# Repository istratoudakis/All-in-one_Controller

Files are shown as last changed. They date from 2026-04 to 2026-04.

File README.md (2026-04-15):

# All-in-One Productivity & AI Controller 🚀
### Developed for ΣΦΗΜΜΥ 17 / Pre-ΣΦΗΜΜΥ 10

A modular hardware-software ecosystem designed to streamline productivity by combining physical controls with a Python-based AI bridge. 

## 🛠 Project Overview
This project features an **ESP32-based controller** that interfaces with a Windows environment. It manages system functions (volume, app control) and integrates **Google Gemini AI** for voice-activated commands and intelligent task parsing.

## ✨ Key Features
- **Hardware Interface:** 13 mechanical buttons & a high-precision rotary encoder.
- **Custom GUI:** A 3.5" TFT (ILI9488) display running optimized C++ firmware.
- **Python Broker:** A robust serial bridge that handles system calls, Spotify API, and Discord integration.
- **AI Integration:** Voice-to-Command processing via Google Gemini AI.
- **Audio Processing:** Real-time noise calibration for high-accuracy voice recognition.

## 📂 Repository Structure
- `/Firmware`: ESP32 C++ source code (Arduino/PlatformIO).
- `/Python_Backend`: The "Broker" script, API handlers, and GUI.
- `/Hardware`: 3D models (.STL) and circuit diagrams.

## ⚙️ Installation & Setup

### 1. Hardware Setup
Flash the ESP32 with the code found in the `/Firmware` directory. Ensure you have the `TFT_eSPI` and `Adafruit_MCP23X17` libraries installed.

### 2. Python Backend
Install the necessary dependencies:
```bash
pip install -r requirements.txt

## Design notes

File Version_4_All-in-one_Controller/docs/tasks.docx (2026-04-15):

Task 1: Το "Serial Bridge" (Επικοινωνία Python-ESP32)

Πρέπει να φτιάξεις έναν κώδικα που "ακούει" συνεχώς τη σειριακή θύρα χωρίς να κολλάει το υπόλοιπο πρόγραμμα.

- Τι να ψάξεις: "Python pyserial read line example", "Python serial.Serial documentation".
- Τι να προσέξεις: Μάθε πώς να ορίζεις το baudrate (συνήθως 115200) και το timeout.
- Πρόκληση: Ψάξε πώς να κάνεις το loop σου "non-blocking" ώστε να μπορείς να κάνεις κι άλλα πράγματα ταυτόχρονα.

Task 2: Master Volume Control (Windows API)

Εδώ θα συνδέσεις το script σου με το λειτουργικό σύστημα.

- Τι να ψάξεις: "Python pycaw change master volume", "pycaw library examples GitHub".
- Τι να προσέξεις: Η pycaw δουλεύει με τιμές σε Decibels (που είναι λογαριθμικές). Ψάξε πώς να τις μετατρέψεις σε ένα απλό ποσοστό 0-100%.
- Βιβλιοθήκη: pycaw, comtypes, ctypes.

Task 3: Media Keys (Spotify Play/Pause/Next)

Πρέπει να προσομοιώσεις το πάτημα των "ειδικών" πλήκτρων του πληκτρολογίου.

- Τι να ψάξεις: "Python pyautogui press media play pause", "Python keyboard library media keys".
- Τι να προσέξεις: Η pyautogui είναι πιο εύκολη, αλλά η βιβλιοθήκη keyboard είναι πιο γρήγορη. Διάλεξε όποια σε βολεύει.

Task 4: Gemini AI Integration

Εδώ θα υλοποιήσεις τη "νοημοσύνη".

- Τι να ψάξεις: "Google Generative AI Python SDK quickstart", "Gemini API key setup".
- Τι να προσέξεις: Δες πώς λειτουργεί το model.generate_content.
- Bonus: Αν θες φωνητική εντολή, ψάξε τη βιβλιοθήκη SpeechRecognition και δες πώς να μετατρέπεις τον ήχο από το μικρόφωνο σε κείμενο (recognize_google).

Task 5: Spotify Web API (Για πληροφορίες τραγουδιού)

Αν θες ο φίλος σου να δείχνει στην οθόνη τον τίτλο του τραγουδιού, η Python πρέπει να τον "τραβήξει" από το Spotify.

- Τι να ψάξεις: "Spotipy documentation", "Spotify Developer Dashboard create app".
- Τι να προσέξεις: Θα χρειαστείς ένα Client ID και ένα Client Secret. Ψάξε τη μέθοδο current_user_playing_track.

Task 6: Το Πρωτόκολλο (Handshake)

Είναι ο τρόπος που θα μιλάς στον φίλο σου.

- Τι να ψάξεις: "String parsing in Arduino", "Python string formatting for serial".
- Task: Όρισε μια δομή. Π.χ. αν στείλεις από την Python [VOL:50], ο φίλος σου στο ESP32 πρέπει να ξέρει να απομονώσει τον αριθμό 50 για να τον δείξει στην οθόνη.

Πώς να ξεκινήσεις σήμερα (χωρίς hardware):

1. Εγκατάστησε το VS Code.
2. Φτιάξε ένα virtual environment (python -m venv venv).
3. Ξεκίνα με το Task 2 (Volume). Είναι το πιο εύκολο για να επιβεβαιώσεις ότι το script σου "μιλάει" στα Windows.  Όσο το project μεγαλώνει και ξεφεύγει από τον κώδικα, η σωστή οργάνωση είναι αυτή που ξεχωρίζει έναν χομπίστα από έναν Engineer. Αν τα έχεις όλα "χύμα", θα χάσεις την μπάλα όταν θα πρέπει να γράψεις την τεχνική αναφορά.
4. Ακολουθεί η επαγγελματική δομή για να ενσωματώσεις έγγραφα, σχέδια και CAD αρχεία:
5. Η Επαγγελματική Δομή Φακέλου
6. Plaintext
7. SmartController/
8. ├── .venv/ # Το virtual environment (Python)
9. ├── src/ # ΜΟΝΟ ο πηγαίος κώδικας (main.py, κλπ)
10. ├── docs/ # Έγγραφα (Τεχνική αναφορά, manual, .docx, .pdf)
11. ├── hardware/ # Τα πάντα για το "σώμα" του controller
12. │ ├── schematics/ # Σχέδια κυκλωμάτων (π.χ. από Wokwi, KiCad, Fritzing)
13. │ ├── cad/ # Αρχεία για το κουτί (3D models, .stl, .step)
14. │ └── datasheets/ # PDF με τα specs των εξαρτημάτων (ESP32, Encoder)
15. ├── assets/ # Εικόνες, εικονίδια για το GUI της οθόνης
16. ├── .gitignore # Λίστα αρχείων που δεν ανεβαίνουν στο Git
17. ├── requirements.txt # Βιβλιοθήκες Python
18. └── README.md # Η κεντρική παρουσίαση του project
20. Γιατί να το κάνεις έτσι;
21. Φάκελος docs/: Εκεί θα έχεις το προσχέδιο της εργασίας σου σε .docx. Όταν τελειώσεις, κάνε "Export as PDF" και κράτα το εκεί ως "Final_Report.pdf". Είναι η εικόνα σου προς τους κριτές.
22. Φάκελος hardware/: * Στο schematics/ αποθήκευσε ένα screenshot από το κύκλωμά σου στο Wokwi.
23. Στο cad/ θα βάλεις τα αρχεία αν αποφασίσετε να εκτυπώσετε το κουτί σε 3D printer.
24. Φάκελος assets/: Αν ο φίλος σου φτιάξει ένα όμορφο logo ή εικονίδια για την OLED οθόνη, πρέπει να είναι κάπου συγκεντρωμένα και όχι μέσα στον φάκελο με τον κώδικα.
26. Πώς να τα φτιάξεις γρήγορα στο VS Code
27. Μπορείς να χρησιμοποιήσεις πάλι το τερματικό (CMD) για να δημιουργήσεις τους φακέλους αστραπιαία:
28. DOS
29. mkdir docs
30. mkdir hardware
31. mkdir hardware\schematics
32. mkdir hardware\cad
33. mkdir hardware\datasheets
34. mkdir assets
35. Pro Tip: Οργάνωση "Versions"
36. Μην ονομάζεις τα αρχεία σου report_v1.docx, report_v2_final.docx. Κράτα ένα όνομα (π.χ. Technical_Report.docx) και αν θέλεις να κρατάς ιστορικό, χρησιμοποίησε το Git (αν το κατέχεις) ή απλά φτιάξε έναν υποφάκελο archive μέσα στο docs.
37. Πώς σου φαίνεται αυτή η δομή; Αν θέλεις, μπορούμε να ξεκινήσουμε να γεμίζουμε τον φάκελο hardware/schematics ορίζοντας το Pinout του ESP32, ώστε να ξέρεις πού θα συνδέσεις το κάθε control!

Είναι φανταστικό που έχετε χωρίσει τους ρόλους έτσι! Αυτό θυμίζει κανονική ομάδα Product Development. Επειδή είστε τρεις και δουλεύετε σε διαφορετικά κομμάτια (Hardware/Simulation, Python/AI, και Production), ο "συνδετικός κρίκος" σας είναι το Interface (η διεπαφή).

Δείτε πώς θα "κουμπώσετε" τη δουλειά σας για να μην χαθείτε:

1. Η Τεχνική Σύνδεση (GitHub ή Shared Folder)

Για να μην στέλνετε αρχεία με email ή Discord (που είναι εφιάλτης), πρέπει να χρησιμοποιήσετε ένα Version Control System.

- Η λύση "Pro": Φτιάξτε ένα GitHub Repository. Εσύ θα ανεβάζεις τον κώδικα Python, ο "Hardware" φίλος σου θα ανεβάζει τα αρχεία του Wokwi ή τον κώδικα C++, και ο "Production" φίλος σου θα ανεβάζει τα assets (εικονίδια, PDFs).
- Η λύση "Easy": Ένας κοινός φάκελος στο Google Drive ή OneDrive, αλλά προσοχή να μην σβήνει ο ένας τα αρχεία του άλλου!

2. Πώς συνδέονται οι ρόλοι σας στην πράξη;

Εσύ (Python & AI Logic)

Είσαι ο "εγκέφαλος". Παίρνεις σήματα από το hardware και δίνεις εντολές στα Windows και το Gemini.

- Τι δίνεις στους άλλους: Πρέπει να πεις στον Hardware φίλο σου: "Θέλω να μου στέλνεις τη λέξη 'GEMINI_REQ' όταν πατιέται το κουμπί του AI".

Ο "Virtual Feedback" Φίλος (Hardware & Simulation)

Είναι υπεύθυνος για το πώς "νιώθει" ο χρήστης τη συσκευή.

- Τι κάνει: Στήνει το Wokwi, τις οθόνες (OLED) και τα κουμπιά.
- Η σύνδεση: Όταν εσύ (Python) παίρνεις μια απάντηση από το Gemini, πρέπει να τη στέλνεις πίσω σε αυτόν (μέσω Serial) για να την εμφανίσει στην εικονική οθόνη του.

Ο "Streaming & Production" Φίλος (Documentation & Presentation)

Αυτός είναι ο "σκηνοθέτης" και ο "συγγραφέας".

- Τι κάνει: Καταγράφει το demo (screen recording του Wokwi και του VS Code), φτιάχνει το βίντεο της παρουσίασης και οργανώνει την τεχνική αναφορά (το .docx που λέγαμε).
- Η σύνδεση: Χρειάζεται από εσένα screenshots του κώδικα και από τον άλλον screenshots του κυκλώματος.

3. Το "Συμβόλαιο" (Communication Protocol)

Για να δουλέψετε ταυτόχρονα, φτιάξτε ένα απλό αρχείο κειμένου (π.χ. protocol.md) όπου θα γράψετε:

Ενέργεια Hardware | Serial Command (προς Python) | Python Action
Πάτημα Κουμπιού 1 | PLAY_PAUSE | pyautogui.press('playpause')
Περιστροφή Encoder | VOL_UP / VOL_DOWN | change_volume(0.05)
Long Press Button 2 | AI_MODE | Ενεργοποίηση Gemini

Πώς να ξεκινήσετε τη σύνδεση ΣΗΜΕΡΑ:

1. Shared Workspace: Φτιάξτε έναν φάκελο στο GitHub ή Drive με τη δομή που συζητήσαμε (src, docs, hardware).
2. Define Pins: Ο Hardware φίλος πρέπει να σου στείλει μια λίστα: "Το κουμπί Play είναι στο Pin 4, το Volume στο Pin 5".
3. The "Mock" Test: Εσύ φτιάξε μια λειτουργία που προσομοιώνει το σήμα του φίλου σου, ώστε να μπορείς να γράφεις κώδικα ακόμα κι αν εκείνος δεν έχει τελειώσει το Wokwi.

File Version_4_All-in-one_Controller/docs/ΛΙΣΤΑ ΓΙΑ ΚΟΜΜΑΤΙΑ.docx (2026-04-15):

### 🛒 Η Τελική Λίστα (Τι πρέπει να παραγγείλετε τώρα)

1. Καπάκια (Knobs) για τα Rotary Encoders: Τα EC11 που έχετε στη λίστα έχουν απλώς έναν γυμνό μεταλλικό άξονα. Χωρίς το πλαστικό ή αλουμινένιο καπάκι, θα σας πονάνε τα δάχτυλα να τα γυρίσετε. Προσθέστε 2 τεμάχια.
2. I/O Expander (Μοντούλα MCP23017 ή PCF8574): Υπερ-απαραίτητο! Ας κάνουμε τα μαθηματικά: 10 κουμπιά + 1 διακόπτης + 6 pins (για τα 2 rotaries) + ~5-6 pins για την οθόνη = 22+ pins. Το ESP32 έχει μεν αρκετά, αλλά κάποια από αυτά (τα λεγόμενα strapping pins όπως τα 0, 2, 5, 12) αν πατηθεί κατά λάθος το κουμπί τους την ώρα που ανοίγει η συσκευή, το ESP32 θα "κολλήσει" και δεν θα κάνει boot. Με ένα MCP23017, γλιτώνετε όλο αυτό το άγχος συνδέοντας τα 10 κουμπιά πάνω του. Προσθέστε 1 τεμάχιο.
3. Κεραμικοί Πυκνωτές 100nF (0.1uF): Είναι πάμφθηνοι (μερικά λεπτά του ευρώ). Θα χρειαστείτε καμιά 20αριά για να τα βάλετε παράλληλα με τα κουμπιά και τα rotaries. Κάνουν το λεγόμενο "Hardware Debouncing" ώστε να μην κάνει "διπλό κλικ" από μόνο του όταν πατάτε το κουμπί μία φορά.
4. Υλικά Συναρμολόγησης (Αν δεν τα έχετε ήδη στο εργαστήριο):
  - 1x Breadboard (Ράστερ): Για να τα συνδέσετε όλα πρόχειρα και να γράψουμε τον κώδικα πριν πιάσετε κολλητήρι.
  - Καλώδια Dupont: 1 σετ Male-to-Male και 1 σετ Female-to-Male για τις δοκιμές.
  - Διάτρητες πλακέτες (Protoboards): 2-3 κομμάτια για να κολλήσετε τα πάντα πάνω τους στο τελικό στάδιο.
  - Pin Headers (Αρσενικά/Θηλυκά): Για να "κουμπώσετε" το ESP32 και την οθόνη πάνω στην πλακέτα χωρίς να τα κολλήσετε μόνιμα (ώστε αν καεί κάτι, να το αλλάξετε εύκολα).

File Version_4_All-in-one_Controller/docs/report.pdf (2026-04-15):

## Σχεδιασμός και Υλοποίηση All-in-one Controller με LCD Screen και Ενσωμάτωση AI

Όνομα Ομάδας: Τα παιδιά από την Πάτρα

### Μέλη:

### Γεώργιος Σικαλιάς

### Ιάσονας Στρατουδάκης

### Κωσταντίνος Παπαδημητρίου

ABSTRACT

Η συγκεκριμένη εργασία ασχολείται με τη σχεδίαση και την υλοποίηση μιας ολοκληρωμένης συσκευής All-in-one Controller, στο πλαίσιο του διαγωνισμού PreΣΦΗΜΜΥ 10 του συνεδρίου ΣΦΗΜΜΥ 17. Η συσκευή έχει ως πυρήνα τον microcontroller ESP32 DevKit V1 σε συνδυασμό με μία οθόνη TFT LCD 3.5” eSPI και έναν I/O Expander 16-bit MCP 23017 πρωτοκόλλου I2C. Η συσκευή επιτρέπει τον έλεγχο του λειτουργικού συστήματος και γενικώς των multimedia, shortcuts για εφαρμογές όπως Spotify, Zoom και Discord αλλά και για το λογισμικό streaming Streamlabs OBS, καθώς και real-time visual response και feedback μέσω της οθόνης. Τα μέσα αλληλεπίδρασης συσκευής-χρήστη περιλαμβάνουν: 13 διακόπτες τύπου button, ένα rotary encoder και διεπαφή φωνητικών εντολών με επεξεργασία φυσικής γλώσσας (NLP) που αξιοποιεί το Gemini AI για βελτιστοποίηση της κατανόησης των εντολών. Ο προγραμματισμός του microcontroller και της οθόνης είναι σε Arduino C++ με τη διασύνδεση του με το λειτουργικό σύστημα και τις εφαρμογές στο PC να έχουν υλοποιηθεί σε Python. Η συσκευή αυτή είναι τοποθετημένη σε ένα 3D printed fully modular κουτί σχεδιασμένο σε περιβάλλον CAD, το οποίο εκτός από την πρακτικότητα του στην συναρμολόγηση-αποσυναρμολόγηση προσδίδει σύγχρονη αισθητική στη συσκευή. Ο συνολικός προϋπολογισμός της συσκευής ανέρχεται στα 61.34€.

CCS CONCEPTS • Computer systems organization ~ Embedded systems • Human-centered computing ~ Interaction devices • Computing methodologies ~ Artificial intelligence

Additional Keywords and Phrases: ESP32, MCP23017, Gemini AI, Google LLM, Διασύνδεση Ανθρώπου-Μηχανής (HCI), Python Serial Bridge, Έλεγχος Πολυμέσων, LCD Screen GUI, Real-time Visual Feedback.

ACM Reference Format:
Γεώργιος Σικαλιάς, Ιάσονας Στρατουδάκης, Κωσταντίνος Παπαδημητρίου. 2026. Σχεδιασμός και Υλοποίηση All-in-one Controller με LCD Screen και Ενσωμάτωση AI. PreΣΦΗΜΜΥ 10, ΣΦΗΜΜΥ 17. Πάτρα, Ελλάδα.

## Contents

### 1 INTRODUCTION

### 1.1 Concept

Με τη συμμετοχή μας στο διαγωνισμό PreΣΦΗΜΜΥ 10 αποφασίσαμε να ασχοληθούμε με τις 3 από τις 4 αναγραφόμενες στην εκφώνηση λειτουργίες (τουλάχιστον 2 υποχρεωτικές):
- PC & Multimedia Control
- Streaming & Production
- Visual Feedback
Η επιλογή αυτών των λειτουργιών έγινε βάσει του μεγάλου impact που έχει στην καθημερινή ψηφιακή ζωή του μηχανικού η απλοποίηση και αυτοματοποίηση των διαδικασιών αυτών. Είναι πράγματι πολύ πρακτικός ο έλεγχος του λειτουργικού συστήματος και των εφαρμογών του μέσω ενός εξωτερικού συγκεντρωμένου Allin-one Controller. Επομένως, θέσαμε ως προτεραιότητα τη σχεδίαση και υλοποίηση των λειτουργιών αυτών με προτεραιότητα την αύξηση της παραγωγικότητας του χρήστη. Φυσικά, λάβαμε υπόψιν μας ως βασικό άξονα το οικονομικό κόστος το οποίο επιβαλλόταν να ελαχιστοποιηθεί, χωρίς όμως να υποβαθμιστεί η συνολική ποιότητα και λειτουργικότητα της συσκευής. Έτσι, δημιουργήσαμε από την αρχή μία value for money ανταγωνιστική συσκευή, η οποία ενσωματώνει ένα μεγάλο πλήθος διεργασιών.

### 1.2 Επιλογή hardware

Ως πυρήνας της συσκευής επιλέχθηκε ο microcontroller ESP32 DevKit V1 επειδή συνδυάζει υψηλή υπολογιστική ισχύ (Dual Core, Clock Speed: 240 MHz, SRAM: 520 KB, Flash Memory: 4 MB) και εξαιρετικά χαμηλό κόστος ( Ενότητα 1.3). Καθώς όμως παρά το μεγάλο πλήθος των pins του ESP32 γρήγορα συνειδητοποιήσαμε ότι αυτά δεν επαρκούσαν, κατευθυνθήκαμε προς την ενσωμάτωση ενός I/O Expander και συγκεκριμένα του MCP 23017 με πρωτόκολλο I2C. Η επιλογή του MCP23017 δεν έγινε μόνο για την εξοικονόμηση pins, αλλά και για τη μείωση της πολυπλοκότητας της καλωδίωσης. Μέσω του διαύλου I2C (Serial Data - SDA, Serial Clock - SCL), ο ESP32 διαχειρίζεται το σύνολο των 13 εισόδων χρησιμοποιώντας μόνο 2 pins, αφήνοντας τους υπόλοιπους πόρους ελεύθερους για την απαιτητική οδήγηση της TFT οθόνης μέσω του πρωτοκόλλου SPI.
Παράλληλα, επειδή θεωρήσαμε πολύ σημαντική την οπτική απεικόνιση, επενδύσαμε ένα σημαντικό μέρος του συνολικού προϋπολογισμού σε μία ποιοτική ευμεγέθη οθόνη 3.5”, ώστε οι πληροφορίες να είναι διακριτές και ευανάγνωστες στο πλαίσιο ενός απλού και user-friendly GUI. Με αυτό τον τρόπο, από ένα απλό panel κουμπιών, η συσκευή απέκτησε τη δυνατότητα να προσφέρει live visual feedback με ανανέωση ανά δευτερόλεπτο για λόγους ακρίβειας και αξιοπιστίας.

### 1.3 Σχεδίαση Software

Καταρχάς, για τα βασικά Multimedia θα έπρεπε να αξιοποιήσουμε τα δεδομένα του λειτουργικού συστήματος (ένταση ήχου, ένταση μικροφώνου, κάμερα, χρήση CPU, RAM GPU). Στη συνέχεια, αποφασίσαμε ότι θα ενσωματώσουμε τις παρακάτω εφαρμογές:
- Spotify
- Discord
- Zoom
- Streamlabs OBS
Για τη διασύνδεση όλων αυτών των εφαρμογών θα έπρεπε να υλοποιήσουμε μία serial bridge, η οποία να επικοινωνεί με τον ESP32 μέσω USB σε micro USB καλωδίου.
Για λόγους πρακτικότητας επιλέξαμε να υλοποιήσουμε τα παραπάνω σε Python στο Visual Studio Code IDE καθώς εκτελούνται αποκλειστικά στο PC, χωρίς όμως αυτό να μας δημιουργήσει προβλήματα με τον χρόνο απόκρισης. Ο κώδικας του ESP32 υλοποιήθηκε σε Arduino C++ στο Arduino IDE και περιλαμβάνει όλες τις λειτουργίες που επιλέξαμε καθώς και δυνατότητα ενσύρματης επικοινωνίας με τον υπολογιστή μέσω του serial bridge.

### 1.4 Hardware Συσκευής και Κοστολόγηση

No. | Όνομα Component | Link | Κόστος
1 | Espressif ESP32D Development Kit Wifi & Bluetooth | https://www.skroutz.gr/s/37404120/Espressif-ESP32D-Development-Kit-WiFi-Bluetooth.html (https://www.skroutz.gr/s/37404120/Espressif-ESP32D-Development-Kit-WiFi-Bluetooth.html) | 9.20€
1 | Οθόνη LCD 3.5” (46751) | https://www.skroutz.gr/s/46180029/Othoni-LCD-3-5-46751.html (https://www.skroutz.gr/s/46180029/Othoni-LCD-3-5-46751.html) | 25.00€
1 | Microchip I/O Expander (MCP23017-E/SP) | https://www.skroutz.gr/s/45257010/Microchip-I-O-Expander-MCP23017-E-SP.html (https://www.skroutz.gr/s/45257010/Microchip-I-O-Expander-MCP23017-E-SP.html) | 4.50€
1 | Rotary Encoder Module with Demo Code Module για Arduino KY-040 | https://www.skroutz.gr/s/40170309/Rotary-Encoder-Module-With-Demo-Code-Module-gia-Arduino-KY-040.html (https://www.skroutz.gr/s/40170309/Rotary-Encoder-Module-With-Demo-Code-Module-gia-Arduino-KY-040.html) | 2.00€
2 | Haitronic Διακόπτης Μπουτόν 10τμχ | https://www.skroutz.gr/s/52173703/Haitronic-Diakoptis-Mpouton-HR0320-10tmch.html (https://www.skroutz.gr/s/52173703/Haitronic-Diakoptis-Mpouton-HR0320-10tmch.html) | 1.00€
2 | Optum Solderless Breadboard (MB-102) | https://www.skroutz.gr/s/30576026/Optum-Solderless-Breadboard-MB-102.html (https://www.skroutz.gr/s/30576026/Optum-Solderless-Breadboard-MB-102.html) | 4.64€
1 | Haitronic Half-Size Solderless Breadboard 400 θέσεων 82x54mm | https://www.skroutz.gr/s/28640210/Haitronic-Half-Size-Solderless-Breadboard-400-theseon-82x54mm.html (https://www.skroutz.gr/s/28640210/Haitronic-Half-Size-Solderless-Breadboard-400-theseon-82x54mm.html) | 1.99€
3 | Dupont M-F Καλώδιο 0.2m OEM478 10τμχ | https://www.skroutz.gr/s/64645470/dupont-m-f-kalodio-0-2m-oem478-10tmch.html (https://www.skroutz.gr/s/64645470/dupont-m-f-kalodio-0-2m-oem478-10tmch.html) | 2.25€
45/65 | Arduino 65pcs Jumper Wire Cable Kit for Solderless Breadboard Connections | https://www.skroutz.gr/s/28756792/Arduino-65pcs-Jumper-Wire-Cable-kit-for-Solderless-Breadboard-Connections.html (https://www.skroutz.gr/s/28756792/Arduino-65pcs-Jumper-Wire-Cable-kit-for-Solderless-Breadboard-Connections.html) | 2.17€

14 | Πυκνωτής Κεραμικός 104 100nf | https://www.skroutz.gr/s/58711482/Pyknotis-Keramikos-104-100nf.html (https://www.skroutz.gr/s/58711482/Pyknotis-Keramikos-104-100nf.html) | 0.70€
0.435kg | Esun PLA 3D Printer Filament 1.75mm Μαύρο 1kg 1τμχ (Spool) | https://www.skroutz.gr/s/59842404/esun-pla-3d-printer-filament-1-75mm-mayro-1kg-1tmch-spool.html (https://www.skroutz.gr/s/59842404/esun-pla-3d-printer-filament-1-75mm-mayro-1kg-1tmch-spool.html) | 6.92€
1 | Ρεύμα/Φθορές 3D Printer | - | 1.00€
1 | Λογισμικό | - | 0.00€
61.34€

### 2 HARDWARE DESIGN

### 2.1 Τροφοδοσία και Ισχύς

Η κύρια τροφοδοσία (5V) γίνεται μέσω του καλωδίου USB σε micro USB από το PC στο ESP32. Το ESP32 εν συνεχεία λειτουργεί ως κόμβος τροφοδοσίας, αφού όλα τα υπόλοιπα components (LCD screen, I/O expander, rotary controller) συνδέονται σε pins του, είτε άμεσα, είτε έμμεσα μέσω breadboard. Επειδή όμως τα υπόλοιπα στοιχεία λειτουργούν στα 3.3V, το ESP32 υποβιβάζει τη τάση στα 3.3V (μέσω LDO AMS1117) και οι συνδέσεις με τα components γίνονται μέσω του pin 3V3.
Για να φιλτράρουμε τον ηλεκτρικό θόρυβο που προκαλείται από τις εναλλαγές του σήματος(από λογικό ‘0’ σε λογικό ‘1’ και αντίστροφα) χρησιμοποιήσαμε κεραμικούς πυκνωτές των 100nF στους διακόπτες τύπου button. Έτσι, αποφεύγεται το bouncing των buttons κατά το press και διασφαλίζεται η αξιοπιστία και η λειτουργικότητα του κυκλώματος.

### 2.2 Διεπαφές Επικοινωνίας

Μεταξύ των components συνυπάρχουν 2 πρωτόκολλα επικοινωνίας:
1. I2C Bus μεταξύ MCP23017 και ESP32 για έλεγχο των pins
2. SPI Bus μεταξύ LCD οθόνης και ESP32 για έλεγχο του GUI της οθόνης Ακολουθεί μία σύντομη επεξήγηση της λειτουργίας των πρωτοκόλλων που αξιοποιήσαμε.

2.2.1 I2C Bus

Το I2C προσφέρει τη δυνατότητα ελέγχου και των 13 κουμπιών με μόνο 2 γραμμές σήματος: την SDA (Serial Data) και την SCL (Serial Clock). Με αυτόν τον τρόπο εξοικονομούνται 11 pins του ESP32 (2 pins αντί για 13), κάτι ιδιαίτερα πρακτικό για τη σχεδίαση του embedded συστήματος. Η επικοινωνία διεξάγεται στα 400kHz, συχνότητα η οποία εξασφαλίζει αμελητέο latency.
Ακολουθεί το κυκλωματικό διάγραμμα των συνδέσεων μεταξύ του MCP23017 και του ESP32:

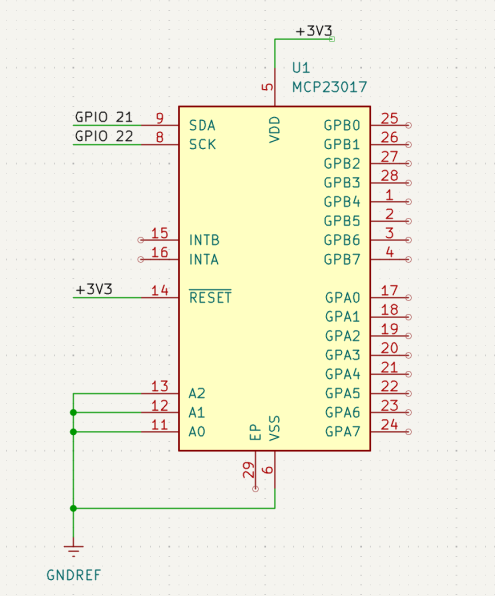
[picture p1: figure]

Συνδέσεις του MCP23017 στο ESP32 [2.2.1]

2.2.2 SPI Bus
Το πρωτόκολλο SPI χρησιμοποιείται για τη μεταφορά μεγάλου όγκου πληροφορίας στην οθόνη (480x320 pixel, αυτόνομα για κάθε pixel). Το SPI χρησιμοποιεί 4 γραμμές σήματος: SCK (Clock), MOSI (Master Out Slave In), CS (Chip Select) και DC (Data/Command). Η επικοινωνία είναι χρονισμένη στα 40MHz, μεγαλύτερη των 400kHz του I2C, κάτι απαραίτητο για να έχουμε real-time visual feedback και συνεπακόλουθα για ομαλή ανανέωση των γραφικών στην οθόνη. Η λειτουργία της οθόνης βασίζεται στον driver ILI9488.

Ακολουθεί το κυκλωματικό διάγραμμα της διασύνδεσης της οθόνης με το ESP32:

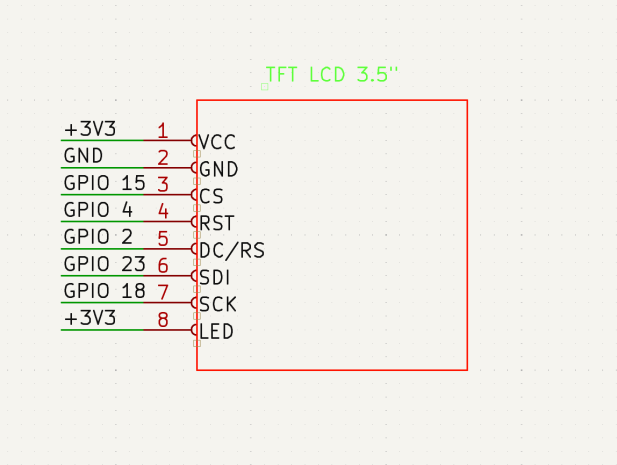
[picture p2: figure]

Συνδέσεις από την οθόνη στο ESP32 [2.2.2]

### 2.3 Διασύνδεση Εισόδων

Έχουμε 2 ειδών εισόδους: απλούς μηχανικούς διακόπτες τύπου button και ένα rotary encoder, οπότε η ανάλυσή μας θα χωριστεί σε δύο μέρη. Στη συνέχεια, θα αναλύσουμε την οργάνωση των κυκλωμάτων ανά breadboard.

2.3.1 Μηχανικοί Διακόπτες (Buttons)

Η συσκευή περιλαμβάνει 13 μηχανικούς διακόπτες, οποίοι είναι συνδεδεμένοι στις GPA και GPB θύρες του MCP23017. Οι διακόπτες λειτουργούν με active-low λογική, δηλαδή η λειτουργία διεκπεραιώνεται στο λογικό ‘0’. Σε συνδυασμό με τους πυκνωτές, το σήμα καθαρίζεται με αποτέλεσμα να μην δημιουργούνται προβλήματα θορύβου.

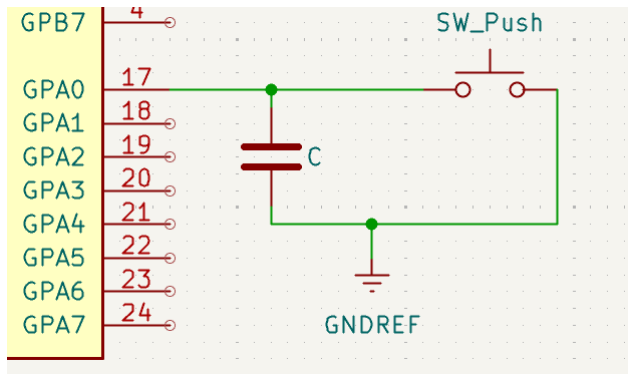
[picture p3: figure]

Κύκλωμα με διακόπτη Button

2.3.2 Περιστροφικός Κωδικοποιητής (Rotary Encoder)

Για τον έλεγχο της έντασης (Volume Up/Down) και την έναρξη/παύση (Play/Pause) χρησιμοποιήθηκε ο rotary encoder. Η λειτουργία play/pause είναι εφάμιλλη με αυτή των buttons. Για τον περιστροφικό διακόπτη όμως έχουμε διαφορετική λειτουργία. Συγκεκριμένα, ο rotary encoder παράγει δύο τετραγωνικά σήματα DT (Data) και CLK (Clock) με διαφορά φάσης 90ο
. Ανάλογα με την κατεύθυνση της περιστροφής (δεξιόστροφη ή αριστερόστροφη) συγκρίνει πιο από τα δύο σήματα αλλάζει κατάσταση πρώτο και επιλέγει αντίστοιχα αύξηση ή μείωση της έντασης του ήχου. Τα pins του rotary encoder είναι απευθείας συνδεδεμένα πάνω στα pins του ESP32 και όχι μέσω του MCP23017, όπως παρακάτω:

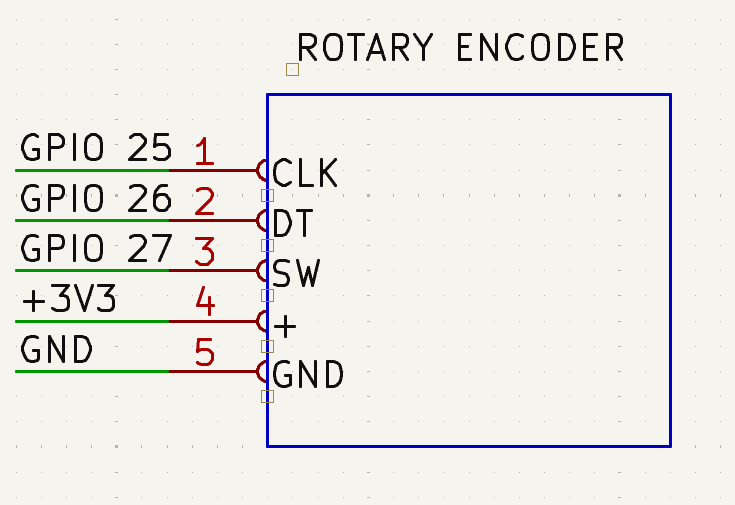
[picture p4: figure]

Συνδέσεις Rotary Encoder σε ESP32

2.3.3 Breadboards

Στην συσκευή μας χρησιμοποιήσαμε 3 breadboards: 2 κλασσικού μεγέθους και ένα του μισού μεγέθους. Στο μικρό κεντρικό breadboard έχουν γίνει οι συνδέσεις του ESP32 με την οθόνη και με το rotary encoder. Στο πάνω κλασσικό breadboard έχουν τοποθετηθεί τα 10 από τα 13 buttons, ενώ στο κάτω έχουν τοποθετηθεί τα 3 επιπλέον buttons και η σύνδεση με το MCP23017.

### 3 C++ FIRMWARE & SERIAL BRIDGE

### 3.1 Δομή Firmware

Ο κώδικας του ESP32 έχει οργανωθεί ούτως ώστε να μην αποτελεί απλά ένα σύνολο εντολών, αλλά να είναι σχεδιασμένο να λειτουργεί ως ένα multitasking σύστημα. Έτσι, για παράδειγμα, η ανανέωση της οθόνης δεν εμποδίζει την λειτουργία των buttons ή του rotary encoder.
Για την υλοποίηση του firmware χρησιμοποιήθηκαν οι βιβλιοθήκες: Wire.h, Adafruit_MCP23X17.h και TFT_eSPI.h.

### 3.2 Διαχείριση εισόδων

Ο ESP32 ελέγχει συνεχώς στον MCP23017 την κατάσταση των buttons και αν κάποιο βρεθεί στο λογικό ‘0’, τότε ενεργοποιεί την αντίστοιχη λειτουργία. Όσον αφορά το rotary encoder, για την αποφυγή απώλειας δεδομένων κατά τη γρήγορη περιστροφή, χρησιμοποιήσαμε external interrupts στα pins του ESP32. Αυτό διασφαλίζει ότι η μεταβλητή της έντασης ενημερώνεται ακαριαία, ανεξάρτητα από το τι κάνει το υπόλοιπο πρόγραμμα.

### 3.3 Σχεδίαση GUI Οθόνης

Όπως αναφέραμε και στην παράγραφο 2.2.2, το SPI είναι ρυθμισμένο στα 40MHz που σε συνδυασμό με την βιβλιοθήκη TFT_eSPI επιτρέπει την ομαλή ανανέωση των pixel της οθόνης. Για να αποφευχθεί το flickering της οθόνης, δεν ανανεώνεται ολόκληρη η οθόνη συνεχώς, αλλά μόνο τα pixel τα οποία αλλάζουν. Η οθόνη έχει χωριστεί σε 5 μέρη:
- PC Multimedia (Volume, Microphone On/Off, Camera On/Off)

- Spotify (Όνομα κομματιού – Καλλιτέχνης, progress bar που αναγράφει real-time τη χρονική στιγμή που βρίσκεται το κομμάτι)
- PC Stats (CPU - RAM - GPU usage)
- Discord (Mute/Unmute, Deafen/Undeafen)
- Gemini/Voice Command Status (Standby, Listening)

### 3.4 Σειριακό Πρωτόκολλο Επικοινωνίας

Σχεδιάσαμε ένα απλό πρωτόκολλο επικοινωνίας της μορφής <TAG:PAYLOAD>, στο οποίο το TAG προσδιορίζει την κατηγορία της εντολής και το PAYLOAD την μεταβληθείσα πληροφορία. Έτσι, με αυτό τον απλό τρόπο μπορεί και μεταβιβάζεται γρήγορα η πληροφορία από το ESP32 στο PC και αντίστροφα.

### 3.5 Λογική Serial Bridge

Η επικοινωνία ESP32 – PC είναι αμφίδρομη, οπότε η ανάλυση μας θα χωριστεί σε δύο διακριτά μέρη: από το microcontroller στο PC και από το PC στο microcontroller.
- ESP32 → PC: Μόλις ο ESP32 ανιχνεύσει κάποια μεταβολή στις εισόδους του κυκλώματος, σύμφωνα με το ενσωματωμένο firmware, οργανώνει την πληροφορία σύμφωνα με το επιλεγμένο σειριακό πρωτόκολλο επικοινωνίας και την προωθεί απευθείας στον υπολογιστή μέσω του καλωδίου USB.
- PC → ESP32: Ο ESP32 συνεχώς παρακολουθεί την σειριακή θύρα USB. Όταν εντοπίσει τον χαρακτήρα “<” διαβάζει το πακέτο πληροφορίας. Στη συνέχεια, δρομολογεί την εκάστοτε αλλαγή στη λειτουργία της συσκευής και ενημερώνει το GUI της οθόνης.
Επειδή η ταχύτητα της σειριακής είναι πολύ υψηλή (115200bps) και έχουμε μεγάλο όγκο δεδομένων, η ανάγνωση των δεδομένων γίνεται χαρακτήρα-χαρακτήρα, ώστε να μην μπλοκάρεται η λειτουργία της υπόλοιπης συσκευής. Επίσης, αν και τα δεδομένα από τις εισόδους αποστέλλονται στο PC σχεδόν ακαριαία, η ενημέρωση του GUI της οθόνης γίνεται ανά δευτερόλεπτο, ρυθμός ικανός να παρέχει μία ικανοποιητική εμπειρία χρήσης και συγχρόνως να μην υπερφορτώνει τον ESP32.
Για την αποφυγή σφαλμάτων, έχουμε δημιουργήσει δύο βασικούς μηχανισμούς ελέγχου:
1. Τα πακέτα πληροφορίας προς ανάγνωση θα πρέπει να αρχίζουν και να τελειώνουν με [ < , >].
2. Αν το TAG δεν ανήκει σε ένα προκαθορισμένο κατάλογο εντολών, τότε η εντολή απορρίπτεται. Τέλος, χρησιμοποιήθηκε λογική multithreading . Συγκεκριμένα, επειδή το voice recording είναι μία διεργασία η οποία δεσμεύει πολλούς πόρους από το ESP32 αυτό εκτελείται σε ένα ανεξάρτητο thread συνεχώς. Έτσι, αποφεύγονται οι διακοπές στην ηχογράφηση που προκαλούνται από τη συμφόρηση εντός του ESP32.

### 4 PYTHON SOFTWARE & API’S

### 4.1 Διαχείριση Λειτουργικού Συστήματος

Ο κώδικας της Python λαμβάνει συγκεκριμένα σήματα από το ESP32 βάσει του σειριακού πρωτοκόλλου επικοινωνίας και εκτελεί άμεσα τις κατάλληλες αλλαγές στο λειτουργικό σύστημα στον υπολογιστή. Συγκεκριμένα, έχουμε τις παρακάτω λειτουργίες:

- Έλεγχος ένταση ήχου: Αξιοποιούμε τη βιβλιοθήκη pycaw (Python Core Audio Windows Library), ώστε να έχουμε πρόσβαση στον ήχο των Windows. Η Python λαμβάνει εντολές από τον rotary encoder και βάσει του payload του πρωτοκόλλου ρυθμίζει το ύψος της έντασης.
- Διαχείριση μικροφώνου: Με τη χρήση του εξωτερικού προγράμματος NirCmd η Python αποκτά έλεγχο στη διαχείριση του global μικροφώνου των Windows.
- Διαχείριση κάμερας: Αξιοποιούμε τις βιβλιοθήκες pyautogui και τη ctypes που ενεργοποιεί ή απενεργοποιεί τη λειτουργία της κάμερας.
- Παρακολούθηση των πόρων: μέσω της βιβλιοθήκης psutil η Python αντλεί πληροφορίες σχετικά με την καταπόνηση του CPU και της RAM, ενώ μέσω της GPUtil την καταπόνηση της GPU.

### 4.2 Διαχείριση Εφαρμογών

Μέσω της Python μπορέσαμε να ενσωματώσουμε τις πιο σημαντικές εφαρμογές που χρησιμοποιεί στην ψηφιακή του καθημερινότητα ένας μηχανικός. Με την ενσωμάτωση αναφερόμαστε σε δημιουργία φυσικών κουμπιών στην συσκευή οι οποίες εκτελούν συντομεύσεις και συνεπικουρούν στην βελτίωση της παραγωγικότητας του χρήστη. Ακολουθεί ανάλυση των επιμέρους εφαρμογών.

4.2.1 Spotify

Για τον έλεγχο του Spotify αξιοποιήσαμε το Spotify Web API (το οποίο απολύτως δωρεάν) και τη βιβλιοθήκη spotipy, η οποία επιτρέπει την άντληση πληροφορίας για το όνομα του κομματιού και αναπαράγεται εκείνη τη στιγμή, το όνομα του καλλιτέχνη, την χρονική στιγμή που βρίσκεται το τραγούδι και τη συνολική διάρκεια.
Επιπλέον, υπάρχει η δυνατότητα play/pause του κομματιού, καθώς και previous/next για καλύτερο έλεγχο του Spotify. Η ενσωμάτωση αυτών των λειτουργιών στο φυσικό κουτί βελτιώνει σημαντικά την εμπειρία του χρήστη, ο οποίος επιθυμεί να συνδυάσει εργασία και μουσική και να έχει τον απόλυτο έλεγχο.

4.2.2 Discord (Καθολικός Έλεγχος Κώφωσης - Deafen)

Λόγω της αυστηρής απαγόρευσης των "Self-Bots" (έλεγχος προσωπικών λογαριασμών μέσω API) από το Discord, η ενσωμάτωση υλοποιήθηκε αναγκαστικά μέσω προσομοίωσης συντομεύσεων σε επίπεδο Λειτουργικού Συστήματος. Στον σχεδιασμό πάρθηκε η απόφαση να προγραμματιστεί αποκλειστικά η εντολή της Κώφωσης (Deafen: F14, εικονικό), καθώς εκμεταλλευόμενοι την εγγενή συμπεριφορά της πλατφόρμας, η Κώφωση επιβάλλει αυτόματα και Σίγαση (Mute). Αυτό εξοικονόμησε πολύτιμα GPIO pins, δημιουργώντας ένα "Panic Button" πλήρους αποκοπής. Επειδή η εντολή λειτουργεί ως διακόπτης εναλλαγής, αναπτύχθηκε μια εσωτερική μηχανή κατάστασης (discord_state = {"deaf": "OFF"}) ώστε η Python να καταγράφει το ιστορικό χρήσης.

4.2.3 Zoom (Raise Hand Integration)

Η αναζήτηση και χρήση της επιλογής "Σήκωμα Χεριού" (Raise Hand) μέσα στα μενού προκαλεί σημαντική απόσπαση προσοχής (Context Switching). Για την επίλυση αυτού του UX προβλήματος, αξιοποιήθηκαν οι καθολικές συντομεύσεις του Zoom. Όταν λαμβάνεται η εντολή ZOOM_HAND από το ESP32, η Python λειτουργεί ως γέφυρα και πυροδοτεί αόρατα τον συνδυασμό alt+y στο παρασκήνιο. Η επιλογή αυτή μετατρέπει μια πολύπλοκη διαδικασία λογισμικού σε μια άμεση, μηχανική (tactile) αλληλεπίδραση. Ο χρήστης αποκτά ένα αποκλειστικό, φυσικό "Κουμπί Συμμετοχής", διεκδικώντας τον λόγο ακαριαία (zero-latency interaction), ενώ συνεχίζει να εργάζεται απρόσκοπτα σε άλλα προγράμματα, ακόμη και αν το Zoom είναι ελαχιστοποιημένο.

4.2.4 OBS (Έλεγχος μέσω OS-Level Hotkeys)

Η διαχείριση του OBS απαιτούσε άμεση απόκριση χωρίς να χάνεται η εστίαση του ενεργού παραθύρου (window focus). Για την αποφυγή διενέξεων με άλλες εφαρμογές (key conflicts) και τη μείωση της κατανάλωσης πόρων, υλοποιήθηκε μια ελαφριά αρχιτεκτονική OS-Level Injection. Μέσω της βιβλιοθήκης keyboard, η Python προσομοιώνει σύνθετες καθολικές συντομεύσεις (Global Hotkeys). Εφαρμόστηκε στρατηγική λογική "Toggle", χρησιμοποιώντας τον ίδιο ακριβώς συνδυασμό (Ctrl+Alt+7) για έναρξη και διακοπή καταγραφής, εξοικονομώντας πλήκτρα. Παράλληλα, ενσωματώθηκε η δυνατότητα άμεσης "τηλεοπτικής" εναλλαγής σκηνών (Ctrl+Alt+8 για "Screen" και Ctrl+Alt+9 για "BRB"). Η λύση αυτή εξασφαλίζει απόλυτη σταθερότητα και μηδενική καθυστέρηση (zero-latency), καθώς το OBS ανταποκρίνεται ακαριαία στο εικονικό πάτημα ακόμα και όταν είναι πλήρως ελαχιστοποιημένο.

### 4.3 Διεπαφή Χρήστη στον υπολογιστή (PC GUI)

Για την παραμετροποίηση του συστήματος από τον τελικό χρήστη, αναπτύχθηκε ένα παραθυρικό περιβάλλον (GUI) με τη χρήση της ενσωματωμένης βιβλιοθήκης tkinter. Το περιβάλλον δεν λειτουργεί απλώς ως οθόνη επιλογών, αλλά διαθέτει εξελιγμένη λογική διαχείρισης συστήματος.

4.3.1 Έξυπνη Ανίχνευση και Εκκίνηση Εφαρμογών

Το GUI έχει τη δυνατότητα να σαρώνει το σύστημα σε πραγματικό χρόνο. Χρησιμοποιώντας την κλήση συστήματος tasklist (μέσω της βιβλιοθήκης subprocess), ανιχνεύει αν εφαρμογές-κλειδιά όπως το Discord (discord.exe), το OBS Studio (obs64.exe) ή το Spotify εκτελούνται ήδη. Κατά το πάτημα του κουμπιού "Εκκίνηση", το πρόγραμμα δεν στέλνει απλά σήματα. Αναλαμβάνει να εκκινήσει αυτόματα όσες εφαρμογές έχει επιλέξει ο χρήστης, αξιοποιώντας τις προεπιλεγμένες διαδρομές (paths) των Windows. Ειδικά για προγράμματα όπως το OBS, το script φροντίζει να ορίσει το σωστό "Working Directory" (π.χ. C:\Program Files\obs-studio\bin\64bit), αποτρέποντας σφάλματα φόρτωσης βιβλιοθηκών (DLLs).

4.3.2 Δυναμική Βαθμονόμηση Μικροφώνου (Microphone Calibration)

Μία από τις μεγαλύτερες καινοτομίες στο κομμάτι του λογισμικού είναι το ενσωματωμένο σύστημα βαθμονόμησης περιβαλλοντικού θορύβου (Noise Calibration).
Η Python μέσω της βιβλιοθήκης pyaudio και του numpy, το σύστημα "ακούει" τον χώρο για 3 δευτερόλεπτα. Στη συνέχεια, τα ηχητικά δεδομένα μετατρέπονται σε πίνακες και υπολογίζεται η μέση ενέργεια του θορύβου (Root Mean Square - RMS). Βάσει του αποτελέσματος RMS, το πρόγραμμα αποφασίζει δυναμικά την ιδανική ευαισθησία. Χρησιμοποιώντας το εξωτερικό εργαλείο nircmd.exe, προσαρμόζει αυτόματα την πραγματική ένταση (Gain) του μικροφώνου στα Windows (π.χ. 95% για απόλυτη ησυχία, 50% για θορυβώδες περιβάλλον). Τα δεδομένα αυτά αποθηκεύονται σε αρχείο noise_profile.json για μελλοντική χρήση από αλγορίθμους φωνητικών εντολών.

### 4.4 Δυναμικά Προσαρμόσιμα Πλήκτρα (Custom Buttons)

Για να διασφαλιστεί η ευελιξία του Controller, το GUI ενσωματώνει σύστημα διαχείρισης 3 ελεύθερα προγραμματιζόμενων πλήκτρων (Custom Slots).
Οι ρυθμίσεις του χρήστη (όνομα πλήκτρου, διαδρομή, κατάσταση) αποθηκεύονται και ανακτώνται
δυναμικά | από | το | αρχείο | custom_buttons.json. | Το | σύστημα | (μέσω | της | συνάρτησης
generate_name_from_content) αναλύει την είσοδο του χρήστη. Εάν η είσοδος είναι URL (π.χ. ξεκινά με http://), αναγνωρίζει αυτόματα γνωστές πλατφόρμες (YouTube, Reddit, Spotify) και ονομάζει το κουμπί ανάλογα. Κατά την εκτέλεση, το ανοίγει στον προεπιλεγμένο browser (μέσω webbrowser). Εάν είναι διαδρομή τοπικού αρχείου, εξάγει το όνομα του εκτελέσιμου και το τρέχει μέσω της εντολής os.startfile().

### 4.5 Ηχογράφηση και Επεξεργασία Φωνής

Για την λειτουργία της φωνητικής εντολής είναι απαραίτητη πρώτα η ηχογράφηση και η ψηφιακή επεξεργασία του σήματος. Επομένως, ας δούμε πιο αναλυτικά τις δύο διεργασίες.

4.5.1 Ηχογράφηση Φωνής

Με το παρατεταμένο πάτημα του κουμπιού της φωνητικής εντολής ενεργοποιείται το μικρόφωνο, έπειτα από επικοινωνία με το ESP32. Ο ήχος συλλέγεται σε chunks σε ξεχωριστό thread, ώστε να αποφεύγεται η παραμόρφωση (audio stuttering), και ακολούθως αποθηκεύεται σε αρχείο raw_command.wav. στον υποφάκελο recordings του φακέλου command.

4.5.2 Επεξεργασία Φωνής

Αρχικά, το πρώτο βήμα είναι ο καθαρισμός του θορύβου με τη χρήση της βιβλιοθήκης noisereduce. Το πρόγραμμα αναλύει το φάσμα συχνοτήτων του σήματος και αφαιρεί το στατικό θόρυβο ο οποίος υπάρχει. Έπειτα, μέσω της βιβλιοθήκης pydub κάνει κανονικοποίηση στο σήμα, ώστε τα ηχητικά των φωνητικών εντολών να έχουν όλα την ίδια ένταση άσχετα με την ένταση της ηχογράφησης και αποθηκεύεται σε αρχείο clean_command.wav στον υποφάκελο processed του commands.

4.5.3 Speech-to-text μέσω της Google

Για να μπορέσει το σύστημα να ανταποκριθεί σε φωνητική εντολή, αυτή θα πρέπει να έχει γίνει κείμενο. Επομένως, αξιοποιήσαμε την βιβλιοθήκη speech_recognition, η οποία είναι από τις καλύτερες (ειδικά στα ελληνικά) λόγω της πιστότητας της. Έτσι, έχουμε την εντολή σε ένα string το οποίο στη συνέχεια είναι πολύ πιο ευέλικτο στη διαχείριση.

### 4.6 Απόκριση σε Φωνητικές Εντολές και Ενσωμάτωση AI

Για την διαχείριση των φωνητικών αιτημάτων έχουμε σχεδιάσει δύο τρόπους επεξεργασίας: τοπική ανάλυση (Local Parsing) ή ευφυής ανάλυση (AI Parsing). Παρακάτω θα δούμε αναλυτικότερα τι προσφέρει κάθε είδος επεξεργασίας. Πριν όμως το στάδιο εκείνο το στάδιο πραγματοποιείται κανονικοποίηση στο string της εντολής, δηλαδή αφαιρούνται οι τόνοι και όλα τα γράμματα γίνονται πεζά, ώστε να αποφεύγονται σφάλματα λόγω διαφορετικού τρόπου γραφής.

4.6.1 Local Parsing

Είναι η ταχύτερη μέθοδος επεξεργασίας που διαθέτει το σύστημα. Ουσιαστικά, το σύστημα αναζητάει ρίζες λέξεων (stemming) μέσα στο string (πχ «δυναμ» αντί για δυνάμωσε, «χαμηλ» αντί για χαμήλωσε) και ανάλογα με το τι θα εντοπίσει η Python, πυροδοτεί την αντίστοιχη μεταβολή και ενημερώνει τον ESP32. Ο λόγος που αναζητούμε ρίζες λέξεων και όχι ολόκληρες λέξεις είναι διότι είναι πολύ συχνό να μην αναγνωρίζονται ακριβώς οι λέξεις, αλλά να διαφοροποιείται το κείμενο που προέρχεται από την ίδια εντολή, ανάλογα με την άρθρωση του χρήστη.
Το πλεονέκτημα αυτής της μεθόδου είναι η μεγάλη ταχύτητα (μικρότερος χρόνος απόκρισης από 0.5 sec), κάτι ιδιαίτερα χρήσιμο για απλές σύντομες εντολές (έως 9 λέξεις). Βέβαια, αν έχουμε δύο ή σε κάποιες περιπτώσεις τρεις υποεντολές σε ένα κείμενο το πολύ 9 λέξεων όπως πχ «Χαμήλωσε την ένταση στο 40 και ξεκίνα το Spotify», ανάλυση πάλι γίνεται τοπικά και ικανοποιούνται και τα δύο αιτήματα. Έτσι, δεν απαιτείται σύνδεση στο διαδίκτυο για απλές εντολές του τύπου «Βάλε την ένταση στο 80» ή «Άνοιξε το μικρόφωνο/κάμερα» και η εκτέλεσή τους είναι ταχύτατη.

4.6.2 AI Processing

Εάν το string της εντολής αριθμεί από 10 λέξεις και πάνω ή δεν αναγνωριστεί κάποια ρίζα λέξης μέσω stemming και οπότε απαιτείται κατανόηση του context της εντολής, το string αποστέλλεται στο Gemini AI μέσω του ομώνυμου API. Για λόγους αξιοπιστίας, δημιουργήσαμε δύο client keys (ένα κύριο, ένα backup) ώστε να αποφεύγονται τα σφάλματα.
Το Gemini λαμβάνει ένα prompt που του εξηγεί το ρόλο του ως ένα «ευφυές» All-in-one Controller, αναγράφει κατά λέξη την εντολή και του ζητάει να απαντήσει τυποποιημένα σε μορφή JSON. Η Python έχει ένα λεξικό με τα αντικείμενα που μας ενδιαφέρουν (Spotify status, Volume, Microphone, κλπ.) σε μορφή JSON, κάτι που βοηθάει στην οργάνωση και στην επικοινωνία με το serial bridge, ειδικά σε σύνθετες εντολές. Το πλεονέκτημα αυτής της μεθόδου είναι οι δυνατότητες όχι μόνο γλωσσικής κατανόησης, αλλά συνολικής κατανόησης πρόθεσης. Δηλαδή, με την εντολή «Δεν ακούω τίποτα», το Gemini AI αντιλαμβάνεται το πρόβλημα (χαμηλή ένταση ήχου) και δίνει τη λύση (ανεβάζει την ένταση του ήχου σημαντικά). Επειδή η απόκρισή του απαιτεί περίπου 1 δευτερόλεπτο, χρόνος διπλάσιος από τον χρόνο του local parsing, επιλέγεται η χρήση του ανάλογα με την πολυπλοκότητα της εντολής.

5 3D PRINTING & DESIGN

### 5.1 Φιλοσοφία και Διαδικασία Σχεδίασης

Η σχεδίαση του περιβλήματος (κουτιού) πραγματοποιήθηκε με κύρια προτεραιότητα η συσκευή να είναι πλήρως modular, δηλαδή χωρισμένη σε πολλά κομμάτια τα οποία συνδέονται μεταξύ τους για να παράγουν το τελικό αποτέλεσμα. Αυτό έγινε για λόγους ευκολίας τόσο στην διαδικασία της εκτύπωσης , καθώς έτσι το κάθε λάθος θα μπορούσε να διορθωθεί εύκολα και γρήγορα, όσο και για εύκολη πρόσβαση στα εσωτερικά της συσκευής κατά την διαδικασία συναρμολόγησης. Επιπλέον αυτό βοήθησε να αποφευχθεί σπατάλη υλικού στην διαδικασία εκτύπωσής καθώς ένα λάθος δεν θα σήμαινε ότι θα έπρεπε να ξεκινήσει η διαδικασία εκτύπωσης ξανά από την αρχή.

Τα επιμέρους κομμάτια σχεδιάστηκαν εξ ολοκλήρου στο πρόγραμμα “Autodesk Fusion” εξαιτίας της ευκολίας που προσφέρει στην δημιουργία λεπτομερών μοντέλων. Η εκτύπωση έγινε σε εκτυπωτή “Ender 3 S1” χρησιμοποιώντας το πλαστικό υλικό PLA. Οι ρυθμίσεις που χρησιμοποιήθηκαν ήταν 20% infill με initial layer speed 0.10 mm/sec. Κατά την κατασκευή των τμημάτων δόθηκε ιδιαίτερη έμφαση στην ποιότητα και στην ακρίβεια διότι με τον τρόπο αυτό θα εξασφαλίζαμε ένα περίβλημα το οποίο δεν θα είχε προβλήματα όχι μόνο στην εμφάνιση αλλά και στην συναρμολόγηση.

### 5.2 Ανατομία Περιβλήματος

Το περίβλημα χωρίστηκε σε βάση (Base Plate , [5.2.1]), 4 μεταξύ τους ιδιαίτερες πλευρές, το άνω κάλυμμα και τα στηρίγματα της οθόνης και του Esp32.
Η βάση είναι ένα ορθογώνιο παραλληλόγραμμο με διαστάσεις 18cm x 16.5cm x 4cm η οποία έχει ως κύρια χαρακτηριστικά τα ανοίγματα τα οποία λειτουργούν ως ειδικές εγκοπές των βάσεων στήριξης των υπολοίπων εξαρτημάτων.

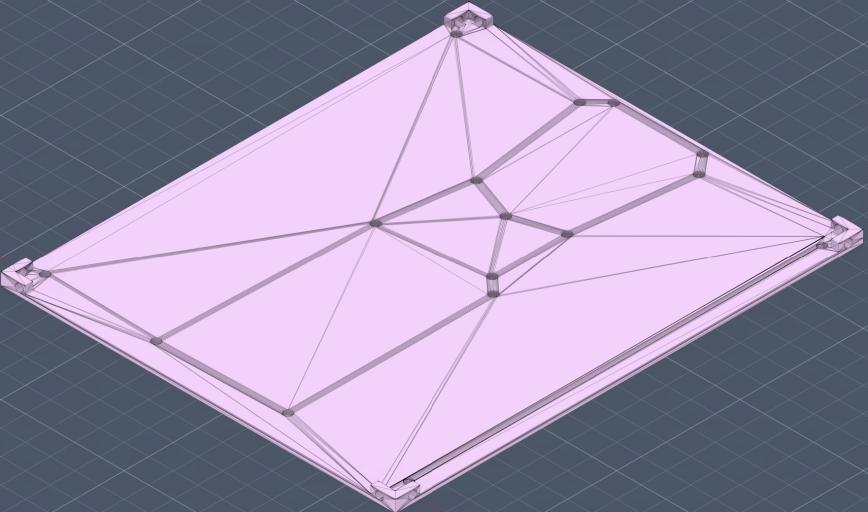
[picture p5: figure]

Βάση [5.2.1]

Οι τέσσερις πλευρές είναι σχεδιασμένες ξεχωριστά διότι η κάθε μια έχει να εξυπηρετήσει διαφορετικές λειτουργίες. Οι δυο πιο μικρές πλευρές, οι οποίες φαίνονται από κάτω στο εξής θα αναφέρονται ως «Πλευρά Α» [5.2.1] και «Πλευρά Β» [5.2.2] έχουν τις μεγαλύτερες διαφορές.

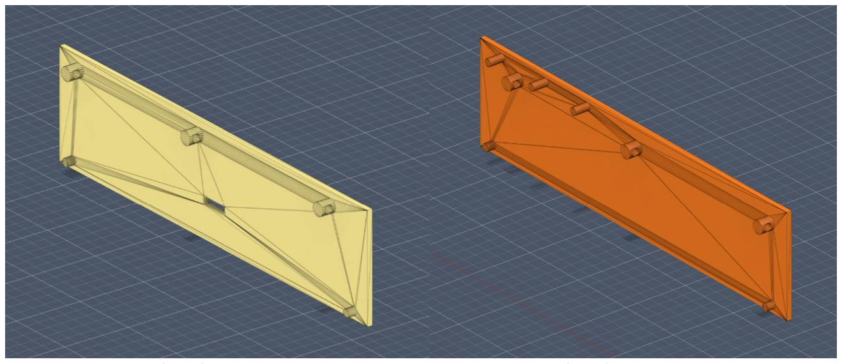
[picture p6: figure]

Πλευρά Α [5.2.2] | Πλευρά Β [5.2.3]

Η πλευρά Α έχει τον ρόλο να στηρίζει τη βάση της οθόνης. Με αυτό υπόψιν ενσωματώθηκαν 3 στηρίγματα τα οποία κουμπώνουν πάνω στη βάση της οθόνης. Η πλευρά Β διαθέτει οπή ώστε να περνάει το καλώδιο που συνδέεται με τον υπολογιστή.
Οι δύο επιμήκεις πλευρές [5.2.3] είναι πανομοιότυπες χωρίς κάποια ιδιαίτερα χαρακτηριστικά πέρα από τις εξοχές που φέρουν για να συνδέονται με τη βάση (Base Plate) και 2 εσοχές οι οποίες συνδέουν τις πλευρές αυτές με το άνω κάλυμμα.

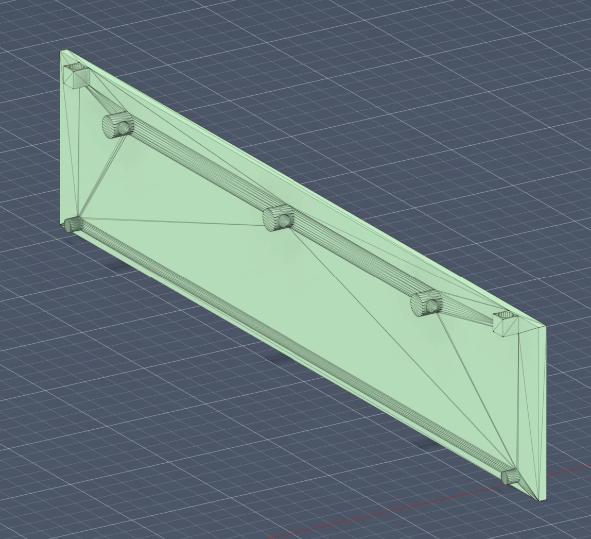
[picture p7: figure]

Επιμήκης πλευρά [5.2.4]

Το άνω κάλυμμα [5.2.5] έχει 14 μικρά ανοίγματα για τα καλύμματα των κουμπιών (Keycaps) και ένα μεγαλύτερο για την οθόνη καθώς και ένα για το ενσωματωμένο rotary encoder. Επιπλέον διαθέτει 4 εξοχές οι οποίες συνδέονται με αντίστοιχες εσοχές στις μακρινές πλευρές.

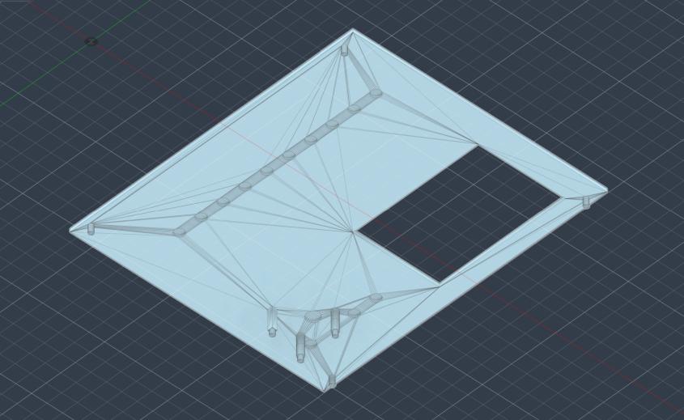
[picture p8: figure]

Άνω κάλυμμα [5.2.5]

Τα στηρίγματα της οθόνης [5.2.6] και του ESP32 [5.2.7] ήταν τα πιο δύσκολα στη σχεδίαση, καθώς απαιτούσαν υψηλή ακρίβεια στους υπολογισμούς των διαστάσεων τους και προσοχή ώστε να σχεδιαστούν με τρόπο που δεν θα επιφέρει ζημιά στα ηλεκτρονικά αλλά ούτε θα εμποδίσει την λειτουργία τους. Επιπλέον για κάθε ένα από τα στηρίγματα απαιτούνταν περαιτέρω κυλινδρικοί αποστάτες (standoffs) ώστε η κατασκευή να είναι πιο στιβαρή.

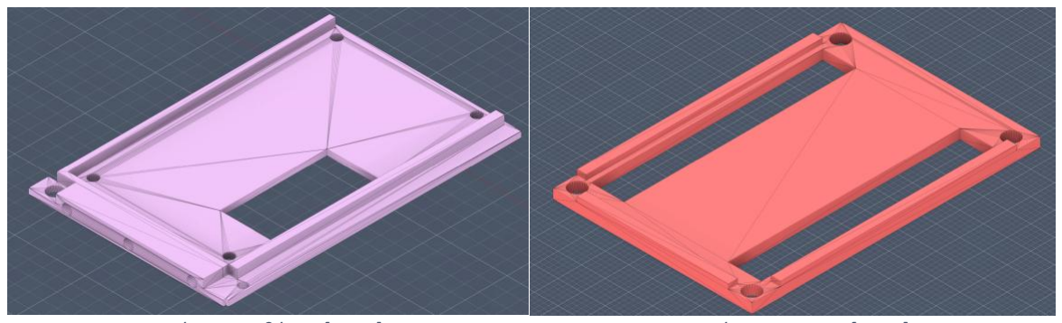
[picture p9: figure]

Στήριγμα Οθόνης [5.2.6] | Στήριγμα ESP32 [5.2.7]

Τα καλύμματα των κουμπιών (keycaps) [5.2.8] σχεδιάστηκαν ξεχωριστά για κάθε κουμπί, ώστε ο χρήστης να αναγνωρίζει άμεσα τη λειτουργία του. Αυτό επιτεύχθηκε μέσω της χάραξης ειδικών συμβόλων στην επιφάνειά τους.

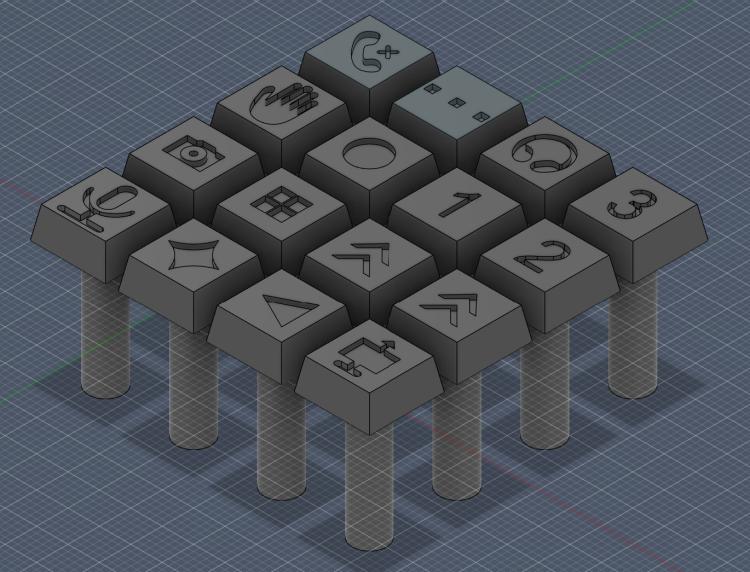
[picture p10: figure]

Καλύμματα κουμπιών (Keycaps) [5.2.8]

### 5.3 Ανοχές και Διορθώσεις κατά τη Συναρμολόγηση

Κατά τη σχεδίαση των επιμέρους τμημάτων λήφθηκε υπόψιν η συμπεριφορά του πλαστικού υλικού PLA, το οποίο έχει την τάση να συρρικνώνεται ελαφρώς μετά την εκτύπωση. Για να μπορούν να ενώνονται τα κομμάτια σωστά μεταξύ τους, εφαρμόστηκαν συγκεκριμένα κενά (ανοχές) στα σημεία εφαρμογής. Συγκεκριμένα, οι τρύπες στις οποίες κουμπώνουν τα εξαρτήματα σχεδιάστηκαν με διάμετρο 0.335cm, ενώ οι προεξοχές που μπαίνουν μέσα σε αυτές σχεδιάστηκαν στα 0.295cm. Αυτό έγινε με κύρια προτεραιότητα να εξασφαλίσουμε ένα καλό κούμπωμα, χωρίς να ασκείται υπερβολική πίεση στο πλαστικό που θα μπορούσε να το σπάσει κατά τη συναρμολόγηση.
Παρόλα αυτά, κατά τη διαδικασία της εκτύπωσης υπήρξαν περιπτώσεις όπου τα κομμάτια δεν εφάρμοζαν τέλεια μεταξύ τους λόγω μικρών ατελειών του 3D εκτυπωτή. Για λόγους ευκολίας και για να αποφευχθεί η σπατάλη χρόνου και υλικού, μια τέτοια αστοχία δεν σήμαινε ότι θα έπρεπε να ξεκινήσει η εκτύπωση ξανά από την αρχή. Αντίθετα, τυχόν λάθη στις διαστάσεις τα διορθώναμε με το χέρι χρησιμοποιώντας λίμα (τρύφτη). Αφαιρώντας τοπικά το πλαστικό που περίσσευε, καταφέραμε να φέρουμε τα εξαρτήματα στην κατάλληλη μορφή ώστε να κουμπώσουν ακριβώς όπως είχαν σχεδιαστεί.

### 6 CONCLUSION

Έχοντας παρουσιάσει το σύνολο της συσκευής μπορούμε να εξάγουμε κάποια συμπεράσματα. Πρώτα απ’ όλα, όσον αφορά το κόστος, αυτό παρατηρούμε ότι ήταν εφικτό να παραμείνει κοντά στα 60€ λόγω της χαμηλής τιμής του ESP32 και του MCP23017, χωρίς όμως να υπάρξει περιορισμός της υπολογιστικής ισχύος. Επιπλέον, η συσκευή μας με την ενσωμάτωση της οθόνης 3.5” που ενημερώνει ζωντανά για τη λειτουργία του υπολογιστή και του AI Voice Assistant καινοτομεί στην αγορά των All-in-one Controllers, επιτυγχάνοντας να διατηρήσει υψηλή λειτουργικότητα, αξιοπιστία και χαμηλό κόστος. Ακόμη, η χρήση PLA και 3D printing, καθώς και η modular σχεδίαση του κελύφους, δίνουν στον χρήστη την ευελιξία της αναβάθμισης και της επισκευής, αλλά και το προνόμιο της μοναδικότητας μέσω της εξατομίκευσης κάθε συσκευής.

### 7 ΒΙΒΛΙΟΓΡΑΦΙΑ – ΣΥΝΔΕΣΜΟΙ

### 7.1 Πηγές

### 1. Hardware & Datasheets (Μικροελεγκτές & ICs)

1. Espressif Systems. ESP32 Series Datasheet. Link (https://www.espressif.com/sites/default/files/documentation/esp32_datasheet_en.pdf)
2. Microchip. MCP23017 16-Bit I/O Expander with I2C Interface. Link (https://ww1.microchip.com/downloads/en/devicedoc/20001952c.pdf)
3. Texas Instruments. Understanding the I2C Bus. Link (https://www.ti.com/lit/an/slva704/slva704.pdf)
4. Analog Devices. SPI Interface Block Guide. Link (https://www.analog.com/en/analog-dialogue/articles/introduction-to-spi-interface.html)

### 2. Arduino Libraries & Firmware (C++)

7. Bodmer. TFT_eSPI Library for ESP32/ESP8266. Link (https://github.com/Bodmer/TFT_eSPI)
8. Adafruit. MCP23017 Arduino Library. Link (https://github.com/adafruit/Adafruit-MCP23017-Arduino-Library)
9. Espressif. ESP-IDF Programming Guide (I2C Driver). Link (https://docs.espressif.com/projects/esp-idf/en/latest/esp32/api-reference/peripherals/i2c.html)

### 3. Python Backend & Automation APIs

11. Python Software Foundation. Python 3.12 Documentation. Link (https://docs.python.org/3/)
12. Gough, A. Pycaw: Python Core Audio Windows Library. Link (https://github.com/AndreMiras/pycaw)
13. Giampaolo, R. psutil: Process and system utilities. Link (https://psutil.readthedocs.io/)
14. Sweigart, A. PyAutoGUI Documentation. Link (https://pyautogui.readthedocs.io/)
15. Spotipy. Lightweight Python library for the Spotify Web API. Link (https://spotipy.readthedocs.io/)

### 4. Digital Signal Processing & AI (NLP)

16. Google AI. Gemini API Documentation & Quickstart. Link (https://ai.google.dev/docs)
17. Sainburg, T. Noisereduce: Noise reduction in Python. Link (https://github.com/timsainb/noisereduce)
18. SpeechRecognition. Library for performing speech recognition. Link (https://pypi.org/project/SpeechRecognition/)
19. Pydub. Audio manipulation with Python. Link (http://pydub.com/)

### 7.2 Σύνδεσμοι

GitHub project link: https://github.com/istratoudakis/-.git

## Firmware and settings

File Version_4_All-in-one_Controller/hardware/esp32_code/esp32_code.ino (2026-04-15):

#include <SPI.h>
#include <TFT_eSPI.h> // Η νέα μας υπερ-βιβλιοθήκη
#include <Wire.h>              // Για την επικοινωνία I2C
#include <Adafruit_MCP23X17.h> // Η βιβλιοθήκη του IO Expander
#include <ESP32Encoder.h>      // ΝΕΑ ΒΙΒΛΙΟΘΗΚΗ: Για το Rotary Encoder!

TFT_eSPI tft = TFT_eSPI(); 
Adafruit_MCP23X17 mcp;         // Δημιουργία του αντικειμένου MCP
ESP32Encoder encoder;          // ΝΕΑ ΠΡΟΣΘΗΚΗ: Δημιουργία του αντικειμένου Encoder

// --- Colours ----
#define BLURPLE tft.color565(85, 104, 255)

// --- BUTTON PINS (Στο MCP23017) ---
const int clkPin = 25; // Rotary CLK
const int dtPin = 26;  // Rotary DT
const int swPin = 27;  // Rotary Button
const int BTN_MEDIA_TOGGLE = 0;
const int BTN_NEXT = 10; // GPA1 next
const int BTN_PREV = 11; // GPA2 previous
const int BTN_MIC_MUTE = 3; // GPA3 mute/unmute
const int BTN_CAMERA = 4; // GPA4 camera on/off
const int BTN_BOSS = 5; // GPA5 boss key

// ΠΡΟΣΘΗΚΗ: 3 Custom Links
const int BTN_LINK_1 = 2; // GPA6 custom link 1
const int BTN_LINK_2 = 13; // GPA7 custom link 2
const int BTN_LINK_3 = 1; // GPB0 custom link 3

// ΝΕΟ ΚΟΥΜΠΙ: Discord Deafen
const int BTN_DISCORD_DEAFEN = 6; // GPB1 για το Deafen

// ΝΕΑ ΚΟΥΜΠΙΑ: OBS Studio
const int BTN_OBS_BRB = 8;     // GPB2 για σκηνή BRB
const int BTN_OBS_SCREEN = 9;  // GPB3 για σκηνή Screen
const int BTN_OBS_REC = 7;  // GPB4 για Record (Start/Stop)

// ΝΕΟ ΚΟΥΜΠΙ: AI Voice Control (Push-to-Talk)
const int BTN_VOICE_AI = 12;    // GPB5

// ΝΕΟ ΚΟΥΜΠΙ: Zoom Raise Hand
const int BTN_ZOOM_HAND = 14;   // GPB6

bool lastNextState = HIGH;
bool lastPrevState = HIGH;
bool lastMediaToggleState = HIGH;
bool lastMicMuteState = HIGH;
bool lastCameraState = HIGH;
bool lastBossState = HIGH;

// ΠΡΟΣΘΗΚΗ: States για τα Custom Links
bool lastLink1State = HIGH;
bool lastLink2State = HIGH;
bool lastLink3State = HIGH;

// ΝΕΟ STATE: Discord Deafen
bool lastDiscordDeafenState = HIGH;

// ΝΕΑ STATES: OBS Studio
bool lastObsBrbState = HIGH;
bool lastObsScreenState = HIGH;
bool lastObsRecordState = HIGH;

//Gemini
bool lastVoiceAiState = HIGH;

// ΝΕΟ ΚΟΥΜΠΙ: Zoom Raise Hand
bool lastZoomHandState = HIGH;

unsigned long lastButtonPress = 0;

// --- GLOBAL VARIABLES ---
int currentScreen = 0; 
bool connection_status = false;

String currentSong = "";
int scrollIndex = 0;
unsigned long lastScrollTime = 0; 

// ==========================================
// IMAGE ARRAYS (32x32)
// ==========================================
const unsigned char spotify_logo [] PROGMEM = {
  0x00, 0x00, 0x00, 0x00, 0x00, 0x07, 0xe0, 0x00, 0x00, 0x3f, 0xfc, 0x00, 0x00, 0xff, 0xff, 0x00,
  0x01, 0xff, 0xff, 0x80, 0x03, 0xff, 0xff, 0xc0, 0x07, 0xff, 0xff, 0xe0, 0x0f, 0xff, 0xff, 0xf0,
  0x1f, 0xc0, 0x03, 0xf8, 0x1f, 0x00, 0x00, 0xf8, 0x3e, 0x0f, 0xf0, 0x7c, 0x3c, 0x7f, 0xfe, 0x3c,
  0x7c, 0xff, 0xff, 0x3e, 0x7d, 0xff, 0xff, 0xbe, 0x7d, 0xe0, 0x07, 0xbe, 0x7f, 0x00, 0x00, 0xfe,
  0x7e, 0x1f, 0xf8, 0x7e, 0xff, 0x7f, 0xfe, 0xff, 0xff, 0xff, 0xff, 0xff, 0xff, 0xff, 0xff, 0xff,
  0xff, 0xe0, 0x07, 0xff, 0xff, 0x00, 0x00, 0xff, 0x7f, 0x3f, 0xfc, 0xfe, 0x7f, 0xff, 0xff, 0xfe,
  0x7f, 0xff, 0xff, 0xfe, 0x3f, 0xff, 0xff, 0xfc, 0x3f, 0xff, 0xff, 0xfc, 0x1f, 0xff, 0xff, 0xf8,
  0x0f, 0xff, 0xff, 0xf0, 0x07, 0xff, 0xff, 0xe0, 0x03, 0xff, 0xff, 0xc0, 0x00, 0xff, 0xff, 0x00
};

const unsigned char volume_logo [] PROGMEM = {
  0x00, 0x00, 0x00, 0x00, 0x00, 0x00, 0x00, 0x00, 0x00, 0x01, 0x80, 0x00, 0x00, 0x03, 0x80, 0x00, 
  0x00, 0x07, 0x86, 0x30, 0x00, 0x0f, 0x86, 0x30, 0x00, 0x1f, 0x86, 0x30, 0x00, 0x3f, 0x86, 0x30, 
  0x07, 0xff, 0x86, 0x30, 0x07, 0xff, 0x86, 0x30, 0x07, 0xff, 0x86, 0x30, 0x07, 0xff, 0x86, 0x30, 
  0x07, 0xff, 0x86, 0x30, 0x07, 0xff, 0x86, 0x30, 0x07, 0xff, 0x86, 0x30, 0x07, 0xff, 0x86, 0x30, 
  0x07, 0xff, 0x86, 0x30, 0x07, 0xff, 0x86, 0x30, 0x07, 0xff, 0x86, 0x30, 0x07, 0xff, 0x86, 0x30, 
  0x00, 0x3f, 0x86, 0x30, 0x00, 0x1f, 0x86, 0x30, 0x00, 0x0f, 0x86, 0x30, 0x00, 0x07, 0x86, 0x30, 
  0x00, 0x03, 0x80, 0x00, 0x00, 0x01, 0x80, 0x00, 0x00, 0x00, 0x00, 0x00, 0x00, 0x00, 0x00, 0x00, 
  0x00, 0x00, 0x00, 0x00, 0x00, 0x00, 0x00, 0x00, 0x00, 0x00, 0x00, 0x00, 0x00, 0x00, 0x00, 0x00
};

const unsigned char microphone_muted [] PROGMEM = {
  0xff, 0xff, 0xff, 0xff, 0xff, 0xff, 0xff, 0xff, 0xff, 0xff, 0xff, 0xfb, 0xff, 0xfc, 0x3f, 0xe3, 
  0xff, 0xf8, 0x1f, 0xe7, 0xff, 0xf0, 0x0f, 0xcf, 0xff, 0xe0, 0x1f, 0x1f, 0xff, 0xe0, 0x3e, 0x3f, 
  0xff, 0xe0, 0x7e, 0x7f, 0xff, 0xe0, 0xfc, 0xff, 0xff, 0xe0, 0xf1, 0xff, 0xff, 0xe3, 0xe3, 0xff, 
  0xff, 0xe7, 0xe7, 0xff, 0xfc, 0xef, 0xcf, 0x3f, 0xfc, 0xff, 0x1f, 0x3f, 0xfc, 0xfe, 0x7f, 0x3f, 
  0xfe, 0xfe, 0x7f, 0x7f, 0xfe, 0xf8, 0xfe, 0x7f, 0xff, 0xf1, 0xfe, 0x7f, 0xff, 0xe3, 0xfc, 0xff, 
  0xff, 0xe7, 0xf9, 0xff, 0xff, 0x8f, 0xc3, 0xff, 0xff, 0x1f, 0x0f, 0xff, 0xfe, 0x3e, 0x7f, 0xff, 
  0xfc, 0x7e, 0x7f, 0xff, 0xf8, 0xfe, 0x7f, 0xff, 0xf1, 0xfe, 0x7f, 0xff, 0xf3, 0xf0, 0x0f, 0xff, 
  0xc7, 0xe0, 0x0f, 0xff, 0xcf, 0xff, 0xff, 0xff, 0xff, 0xff, 0xff, 0xff, 0xff, 0xff, 0xff, 0xff
};

const unsigned char microphone_unmuted [] PROGMEM = {
  0xff, 0xff, 0xff, 0xff, 0xff, 0xfc, 0x3f, 0xff, 0xff, 0xf0, 0x0f, 0xff, 0xff, 0xf0, 0x0f, 0xff, 
  0xff, 0xe0, 0x07, 0xff, 0xff, 0xe0, 0x07, 0xff, 0xff, 0xe0, 0x07, 0xff, 0xff, 0xe0, 0x07, 0xff, 
  0xff, 0xe0, 0x07, 0xff, 0xff, 0xe0, 0x07, 0xff, 0xff, 0xe0, 0x07, 0xff, 0xff, 0xe0, 0x07, 0xff, 
  0xff, 0xe0, 0x07, 0xff, 0xff, 0xe0, 0x07, 0xff, 0xfe, 0x60, 0x06, 0x7f, 0xfe, 0x60, 0x06, 0x7f, 
  0xfe, 0x60, 0x06, 0x7f, 0xfe, 0x60, 0x06, 0x7f, 0xfe, 0x70, 0x0e, 0x7f, 0xfe, 0x30, 0x0c, 0x7f, 
  0xff, 0x3c, 0x3c, 0xff, 0xff, 0x9f, 0xf9, 0xff, 0xff, 0x87, 0xe1, 0xff, 0xff, 0xe0, 0x07, 0xff, 
  0xff, 0xf0, 0x0f, 0xff, 0xff, 0xfe, 0x7f, 0xff, 0xff, 0xfe, 0x7f, 0xff, 0xff, 0xfe, 0x7f, 0xff, 
  0xff, 0xfe, 0x7f, 0xff, 0xff, 0x80, 0x01, 0xff, 0xff, 0x80, 0x01, 0xff, 0xff, 0xff, 0xff, 0xff
};

const unsigned char cam_logo [] PROGMEM = {
  0x00, 0x00, 0x00, 0x00, 0x00, 0x00, 0x00, 0x00, 0x00, 0x0f, 0xf0, 0x00, 0x00, 0x1f, 0xf8, 0x00,
  0x00, 0x3f, 0xfc, 0x00, 0x0f, 0xff, 0xff, 0xf0, 0x1f, 0xff, 0xff, 0xf8, 0x3f, 0xff, 0xff, 0xfc,
  0x3f, 0xff, 0xff, 0xfc, 0x3f, 0xf8, 0x1f, 0xfc, 0x3f, 0xf0, 0x0f, 0xfc, 0x3f, 0xe0, 0x07, 0xfc,
  0x3f, 0xc0, 0x03, 0xfc, 0x3f, 0xc0, 0x03, 0xfc, 0x3f, 0xc0, 0x03, 0xfc, 0x3f, 0xe0, 0x07, 0xfc,
  0x3f, 0xf0, 0x0f, 0xfc, 0x3f, 0xf8, 0x1f, 0xfc, 0x3f, 0xff, 0xff, 0xfc, 0x3f, 0xff, 0xff, 0xfc,
  0x3f, 0xff, 0xff, 0xfc, 0x1f, 0xff, 0xff, 0xf8, 0x0f, 0xff, 0xff, 0xf0, 0x00, 0x00, 0x00, 0x00,
  0x00, 0x00, 0x00, 0x00, 0x00, 0x00, 0x00, 0x00, 0x00, 0x00, 0x00, 0x00, 0x00, 0x00, 0x00, 0x00,
  0x00, 0x00, 0x00, 0x00, 0x00, 0x00, 0x00, 0x00, 0x00, 0x00, 0x00, 0x00, 0x00, 0x00, 0x00, 0x00
};

const unsigned char discord_logo [] PROGMEM = {
  0x00, 0x00, 0x00, 0x00, 0x00, 0x00, 0x00, 0x00, 0x00, 0x00, 0x00, 0x00, 0x00, 0x00, 0x00, 0x00, 
  0x00, 0x00, 0x00, 0x00, 0x00, 0x00, 0x00, 0x00, 0x00, 0x00, 0x00, 0x00, 0x00, 0x00, 0x00, 0x00, 
  0x00, 0x00, 0x00, 0x00, 0x00, 0x00, 0x00, 0x00, 0x00, 0x00, 0x00, 0x00, 0x00, 0x00, 0x00, 0x00, 
  0x00, 0x00, 0x00, 0x00, 0x00, 0x00, 0x00, 0x00, 0x00, 0x00, 0x00, 0x00, 0x00, 0x00, 0x00, 0x00, 
  0x00, 0x00, 0x00, 0x00, 0x00, 0x00, 0x00, 0x00, 0x00, 0x00, 0x00, 0x00, 0x00, 0x00, 0x00, 0x00, 
  0x00, 0x00, 0x00, 0x00, 0x00, 0x00, 0x00, 0x00, 0x00, 0x00, 0x00, 0x00, 0x00, 0x00, 0x00, 0x00, 
  0x00, 0x00, 0x00, 0x00, 0x00, 0x00, 0x00, 0x00, 0x00, 0x00, 0x00, 0x00, 0x00, 0x00, 0x00, 0x00, 
  0x00, 0x00, 0x00, 0x00, 0x00, 0x00, 0x00, 0x00, 0x00, 0x00, 0x00, 0x00, 0x00, 0x00, 0x00, 0x00, 
  0x00, 0x00, 0x01, 0xe0, 0x07, 0x80, 0x00, 0x00, 0x00, 0x00, 0x0f, 0xe0, 0x07, 0xf8, 0x00, 0x00, 
  0x00, 0x00, 0x7f, 0xff, 0xff, 0xfe, 0x00, 0x00, 0x00, 0x00, 0xff, 0xff, 0xff, 0xff, 0x00, 0x00, 
  0x00, 0x00, 0xff, 0xff, 0xff, 0xff, 0x00, 0x00, 0x00, 0x01, 0xff, 0xff, 0xff, 0xff, 0x80, 0x00, 
  0x00, 0x01, 0xff, 0xff, 0xff, 0xff, 0xc0, 0x00, 0x00, 0x03, 0xff, 0xff, 0xff, 0xff, 0xc0, 0x00, 
  0x00, 0x07, 0xff, 0xff, 0xff, 0xff, 0xe0, 0x00, 0x00, 0x07, 0xff, 0xff, 0xff, 0xff, 0xe0, 0x00, 
  0x00, 0x07, 0xff, 0xff, 0xff, 0xff, 0xe0, 0x00, 0x00, 0x0f, 0xff, 0xff, 0xff, 0xff, 0xf0, 0x00, 
  0x00, 0x0f, 0xff, 0xff, 0xff, 0xff, 0xf0, 0x00, 0x00, 0x0f, 0xff, 0xff, 0xff, 0xff, 0xf0, 0x00, 
  0x00, 0x1f, 0xfe, 0x1f, 0xf8, 0x7f, 0xf8, 0x00, 0x00, 0x1f, 0xfc, 0x0f, 0xf0, 0x3f, 0xf8, 0x00, 
  0x00, 0x1f, 0xfc, 0x0f, 0xf0, 0x3f, 0xf8, 0x00, 0x00, 0x1f, 0xfc, 0x0f, 0xf0, 0x1f, 0xf8, 0x00, 
  0x00, 0x1f, 0xfc, 0x0f, 0xf0, 0x1f, 0xf8, 0x00, 0x00, 0x1f, 0xfc, 0x0f, 0xf0, 0x3f, 0xf8, 0x00, 
  0x00, 0x3f, 0xfe, 0x1f, 0xf8, 0x7f, 0xfc, 0x00, 0x00, 0x3f, 0xff, 0xff, 0xff, 0xff, 0xfc, 0x00, 
  0x00, 0x3f, 0xff, 0xff, 0xff, 0xff, 0xfc, 0x00, 0x00, 0x3f, 0xff, 0xff, 0xff, 0xff, 0xfc, 0x00, 
  0x00, 0x3f, 0xff, 0xff, 0xff, 0xff, 0xfc, 0x00, 0x00, 0x3f, 0xff, 0xff, 0xff, 0xff, 0xfc, 0x00, 
  0x00, 0x1f, 0xfb, 0xff, 0xff, 0xdf, 0xf8, 0x00, 0x00, 0x0f, 0xfc, 0xff, 0xff, 0x3f, 0xf0, 0x00, 
  0x00, 0x07, 0xff, 0x03, 0xc0, 0xff, 0xe0, 0x00, 0x00, 0x01, 0xff, 0x00, 0x00, 0xff, 0x80, 0x00, 
  0x00, 0x00, 0x7e, 0x00, 0x00, 0x7e, 0x00, 0x00, 0x00, 0x00, 0x1e, 0x00, 0x00, 0x78, 0x00, 0x00, 
  0x00, 0x00, 0x00, 0x00, 0x00, 0x00, 0x00, 0x00, 0x00, 0x00, 0x00, 0x00, 0x00, 0x00, 0x00, 0x00, 
  0x00, 0x00, 0x00, 0x00, 0x00, 0x00, 0x00, 0x00, 0x00, 0x00, 0x00, 0x00, 0x00, 0x00, 0x00, 0x00, 
  0x00, 0x00, 0x00, 0x00, 0x00, 0x00, 0x00, 0x00, 0x00, 0x00, 0x00, 0x00, 0x00, 0x00, 0x00, 0x00, 
  0x00, 0x00, 0x00, 0x00, 0x00, 0x00, 0x00, 0x00, 0x00, 0x00, 0x00, 0x00, 0x00, 0x00, 0x00, 0x00, 
  0x00, 0x00, 0x00, 0x00, 0x00, 0x00, 0x00, 0x00, 0x00, 0x00, 0x00, 0x00, 0x00, 0x00, 0x00, 0x00, 
  0x00, 0x00, 0x00, 0x00, 0x00, 0x00, 0x00, 0x00, 0x00, 0x00, 0x00, 0x00, 0x00, 0x00, 0x00, 0x00, 
  0x00, 0x00, 0x00, 0x00, 0x00, 0x00, 0x00, 0x00, 0x00, 0x00, 0x00, 0x00, 0x00, 0x00, 0x00, 0x00, 
  0x00, 0x00, 0x00, 0x00, 0x00, 0x00, 0x00, 0x00, 0x00, 0x00, 0x00, 0x00, 0x00, 0x00, 0x00, 0x00
};

const unsigned char undeafened [] PROGMEM = {
  0xff, 0xff, 0xff, 0xff, 0xff, 0xff, 0xff, 0xff, 0xff, 0xff, 0xff, 0xff, 0xff, 0xe0, 0x07, 0xff, 
  0xff, 0x80, 0x01, 0xff, 0xff, 0x01, 0x80, 0xff, 0xfe, 0x1f, 0xf8, 0x7f, 0xfc, 0x3f, 0xfc, 0x3f, 
  0xf8, 0x7f, 0xfe, 0x1f, 0xf0, 0xff, 0xff, 0x0f, 0xf1, 0xff, 0xff, 0x8f, 0xe3, 0xff, 0xff, 0xc7, 
  0xe3, 0xff, 0xff, 0xc7, 0xe3, 0xff, 0xff, 0xc7, 0xe3, 0xff, 0xff, 0xc7, 0xe7, 0xff, 0xff, 0xe7, 
  0xe7, 0xff, 0xff, 0xe7, 0xe7, 0xff, 0xff, 0xe7, 0xe7, 0xff, 0xff, 0xe7, 0xe7, 0xff, 0xff, 0xe7, 
  0xe0, 0x3f, 0xfc, 0x07, 0xe0, 0x3f, 0xfc, 0x07, 0xe0, 0x1f, 0xf8, 0x07, 0xe0, 0x1f, 0xf8, 0x07, 
  0xe0, 0x1f, 0xf8, 0x07, 0xe0, 0x1f, 0xf8, 0x07, 0xe0, 0x1f, 0xf8, 0x07, 0xe0, 0x1f, 0xf8, 0x07, 
  0xe0, 0x3f, 0xfc, 0x07, 0xff, 0xff, 0xff, 0xff, 0xff, 0xff, 0xff, 0xff, 0xff, 0xff, 0xff, 0xff
};

const unsigned char deafened [] PROGMEM = {
  0xff, 0xff, 0xff, 0xff, 0xff, 0xf8, 0x07, 0xff, 0xff, 0xe0, 0x01, 0xff, 0xff, 0x80, 0xe0, 0x7f, 
  0xff, 0x87, 0xfc, 0x3f, 0xef, 0x9f, 0xfe, 0x1f, 0xc7, 0xff, 0xff, 0x0f, 0xe3, 0xff, 0xff, 0x8f, 
  0xf1, 0xff, 0xff, 0xc7, 0xf8, 0xff, 0xff, 0xc7, 0xf8, 0x7f, 0xff, 0xe7, 0xf8, 0x3f, 0xff, 0xe3, 
  0xf9, 0x1f, 0xff, 0xe3, 0xf9, 0x8f, 0xff, 0xe3, 0xf9, 0xc7, 0xff, 0xe3, 0xf9, 0xe3, 0xff, 0xe3, 
  0xf8, 0xe1, 0xff, 0xe3, 0xf8, 0x00, 0xfc, 0x03, 0xf8, 0x04, 0x7c, 0x03, 0xf8, 0x06, 0x3e, 0x03, 
  0xf8, 0x07, 0x1f, 0x03, 0xf8, 0x07, 0x8f, 0x83, 0xf8, 0x07, 0xc7, 0xc3, 0xf8, 0x07, 0xe3, 0xe3, 
  0xf8, 0x07, 0xf1, 0xf3, 0xf8, 0x07, 0xf8, 0xff, 0xf8, 0x07, 0xfc, 0x7f, 0xff, 0xff, 0xfe, 0x3f, 
  0xff, 0xff, 0xff, 0x1f, 0xff, 0xff, 0xff, 0xcf, 0xff, 0xff, 0xff, 0xdf, 0xff, 0xff, 0xff, 0xff
};

// ==========================================
// SCREEN DRAWING FUNCTIONS
// ==========================================

void drawBootScreen() {
  tft.fillScreen(TFT_BLACK); 
  
  if (connection_status == false) {
    tft.setTextColor(TFT_RED); 
    tft.setTextSize(3);             
    tft.setCursor(90, 60);         
    tft.print("Connection Status");

    tft.fillRect(100, 120, 280, 80, TFT_RED);
    tft.setTextColor(TFT_BLACK); 
    tft.setTextSize(3);              
    tft.setCursor(110, 145);          
    tft.print("NOT ESTABLISHED");
  } else {
    tft.setTextColor(TFT_GREEN); 
    tft.setTextSize(3);             
    tft.setCursor(80, 60);         
    tft.print("Connection Status");

    tft.fillRect(100, 120, 280, 80, TFT_GREEN);
    tft.setTextColor(TFT_WHITE); 
    tft.setTextSize(3);              
    tft.setCursor(140, 145);          
    tft.print("ESTABLISHED");
    delay(1000);
    drawMainScreen();
  }
}

void drawMainScreen() {
  tft.fillScreen(TFT_BLACK); 

  // --- ΑΡΙΣΤΕΡΟ ΚΟΥΤΙ: PC SYSTEM (Λευκό) ---
  tft.drawRect(0, 0, 238, 320, TFT_WHITE); 
  tft.fillRect(2, 2, 234, 316, TFT_WHITE);

  // Volume UI
  tft.drawBitmap(20, 20, volume_logo, 32, 32, TFT_BLACK);
  tft.drawRect(70, 31, 140, 10, TFT_BLACK); 

  // Mic UI (Defaults to UNMUTED)
  tft.drawBitmap(25, 120, microphone_unmuted, 32, 32, TFT_BLACK);
  tft.fillRect(20, 160, 50, 30, TFT_WHITE); 
  tft.setTextSize(3);
  tft.setTextColor(TFT_GREEN); 
  tft.setCursor(22, 165);
  tft.print("ON");

  // Cam UI
  tft.drawBitmap(145, 120, cam_logo, 32, 32, TFT_BLACK);
  tft.fillRect(140, 160, 60, 30, TFT_WHITE);
  tft.setTextColor(TFT_RED);
  tft.setCursor(140, 165);
  tft.print("OFF");

  // --- ΔΕΞΙ ΚΟΥΤΙ ΠΑΝΩ: MULTIMEDIA (Μαύρο) ---
  tft.drawRect(238, 0, 242, 160, TFT_WHITE); 
  tft.fillRect(240, 2, 238, 156, TFT_BLACK);

  // Spotify UI
  tft.drawBitmap(250, 20, spotify_logo, 32, 32, TFT_GREEN);
  tft.drawRect(250, 110, 210, 10, TFT_WHITE);

  // Spotify Timestamps
  tft.setTextSize(2);
  tft.setTextColor(TFT_WHITE);
  tft.setCursor(250, 130);
  tft.print("0:00");
  tft.setCursor(410, 130);
  tft.print("0:00");

  // --- ΔΕΞΙ ΚΟΥΤΙ ΚΑΤΩ: DISCORD AREA (Blurple) ---
  tft.drawRect(238, 160, 242, 160, TFT_WHITE); 
  tft.fillRect(240, 162, 238, 156, BLURPLE);

  // Main Discord Identity Logo 
  tft.drawBitmap(260, 205, discord_logo, 64, 64, TFT_WHITE);

  // Status Logo (Undeafened by default)
  tft.drawBitmap(380, 220, undeafened, 32, 32, TFT_WHITE); 
}

// ==========================================
// SETUP
// ==========================================
void setup() {
  Serial.begin(115200);
  delay(1000); 
  Serial.println("--- STARTING BOOT ---");

  // --- ΑΡΧΙΚΟΠΟΙΗΣΗ ΤΟΥ IO EXPANDER ---
  if (!mcp.begin_I2C()) {
    Serial.println("❌ ΣΦΑΛΜΑ: Το MCP23017 δεν βρέθηκε! (I2C Error)");
  } else {
    Serial.println("✅ MCP23017 Initialized!");
    mcp.pinMode(BTN_MEDIA_TOGGLE, INPUT_PULLUP);
    mcp.pinMode(BTN_NEXT, INPUT_PULLUP);
    mcp.pinMode(BTN_PREV, INPUT_PULLUP);
    mcp.pinMode(BTN_MIC_MUTE, INPUT_PULLUP);
    mcp.pinMode(BTN_CAMERA, INPUT_PULLUP);
    mcp.pinMode(BTN_BOSS, INPUT_PULLUP);
    
    // ΠΡΟΣΘΗΚΗ: Setup για τα Custom Buttons
    mcp.pinMode(BTN_LINK_1, INPUT_PULLUP);
    mcp.pinMode(BTN_LINK_2, INPUT_PULLUP);
    mcp.pinMode(BTN_LINK_3, INPUT_PULLUP);

    // ΝΕΟ: Setup για το Discord Deafen
    mcp.pinMode(BTN_DISCORD_DEAFEN, INPUT_PULLUP);

    // ΝΕΟ: Setup για τα OBS Buttons
    mcp.pinMode(BTN_OBS_BRB, INPUT_PULLUP);
    mcp.pinMode(BTN_OBS_SCREEN, INPUT_PULLUP);
    mcp.pinMode(BTN_OBS_REC, INPUT_PULLUP);

    // ΝΕΟ: Setup για το AI Voice Button
    mcp.pinMode(BTN_VOICE_AI, INPUT_PULLUP);

    // ΝΕΟ: Setup για το Zoom Raise Hand
    mcp.pinMode(BTN_ZOOM_HAND, INPUT_PULLUP);
  }

  // --- ΝΕΑ ΑΡΧΙΚΟΠΟΙΗΣΗ ROTARY ENCODER ---
  ESP32Encoder::useInternalWeakPullResistors = puType::up; // Ενεργοποιεί τις εσωτερικές αντιστάσεις
  encoder.attachHalfQuad(dtPin, clkPin);           // Συνδέει τα pins στο hardware
  encoder.clearCount();                            // Μηδενίζει τον μετρητή

  pinMode(swPin, INPUT_PULLUP); // Το κουμπί (πάτημα) του rotary μένει ως έχει

  tft.begin();
  tft.setRotation(1); 
  
  tft.fillScreen(TFT_WHITE); 
  delay(200);
  tft.fillScreen(TFT_BLACK); 
  delay(200);
  
  Serial.println("Display Initialized");
  drawBootScreen();
}
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

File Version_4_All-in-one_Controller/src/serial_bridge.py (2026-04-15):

import serial
import re
import time
import keyboard
import sys
import ctypes
import threading
import warnings
warnings.filterwarnings("ignore", message="Couldn't find ffmpeg or avconv.*")

# --- ΟΙ ΝΕΟΙ HANDLERS ΣΟΥ ΕΝΕΡΓΟΙ ---
from zoom_handler import handle_zoom
from discord_handler_keys import handle_discord_shortcuts
from custom_keys_handler import CustomLinks
from gui_handler import launch_apps_gui
from obs_handler import open_obs, set_brb_scene, set_screen_scene, toggle_recording

# --- Εισαγωγή των κεντρικών λειτουργιών της ομάδας ΕΝΕΡΓΟΙ ---
from pc_controls import boss_key, toggle_camera, set_volume, get_pc_volume, media_play_pause, get_hardware_stats
from spotify_handler import get_spotify_detailed_data, spotify_control
from discord_handler import start_discord_rpc, get_discord_state
from voice_recorder import VoiceRecorder
from voice_processor import convert_voice_to_text
from ai_handler import parse_voice_command

PORT = sys.argv[1] if len(sys.argv) > 1 else "COM9" 
BAUD_RATE = 115200

def background_audio_worker(recorder):
    """Αυτό το Thread τρέχει ΠΑΝΤΑ και κοιτάει αν πρέπει να γράψει ήχο"""
    while True:
        if recorder.is_recording:
            recorder.record_chunk()
        else:
            time.sleep(0.01) # Ξεκούραση της CPU όταν δεν γράφουμε

# --- ΕΝΕΡΓΟ: AI Commands Logic ---
def execute_ai_commands(commands, ser):
    if not commands or "error" in commands: return
    
    # Spotify Control
    if commands.get('spotify') != "NONE":
        spotify_control(commands['spotify'])

    # Global Media Toggle (General)
    app_cmds = commands.get('app_control', [])
    if isinstance(app_cmds, list):
        for cmd in app_cmds:
            if cmd == "MEDIA_TOGGLE":
                media_play_pause() # Καλεί την pyautogui.press('playpause')
            elif "ZOOM" in cmd: handle_zoom(cmd)
            elif "DISCORD" in cmd: handle_discord_shortcuts(cmd)
            elif "OBS" in cmd: open_obs()

    # Volume Control
    if commands.get('volume') is not None:
        set_volume(commands['volume'])
        if ser: ser.write(f"<VOL:{commands['volume']}>\n".encode('utf-8'))
    
    # Boss Key
    if commands.get('boss_key'):
        boss_key()
    
    # Camera
    if commands.get('camera') == "TOGGLE":
        toggle_camera()

    # App Control (Discord/Zoom/OBS)
    app_cmds = commands.get('app_control', [])
    if isinstance(app_cmds, list):
        for cmd in app_cmds:
            if "ZOOM" in cmd: handle_zoom(cmd)
            elif "DISCORD" in cmd: handle_discord_shortcuts(cmd)
            elif "OBS" in cmd: open_obs()
    
    # Feedback στην οθόνη του ESP32
    if ser and commands.get('feedback'):
        ser.write(f"{commands['feedback']}\n".encode('utf-8'))

def start_bridge(port_name=PORT):
    recorder = VoiceRecorder()
    
    # --- ΝΕΑ ΠΡΟΣΘΗΚΗ: Ξεκινάμε το Thread της ηχογράφησης εδώ ---
    audio_thread = threading.Thread(target=background_audio_worker, args=(recorder,), daemon=True)
    audio_thread.start()

    ser = None
    
    last_vol = -1
    last_discord_mic = ""
    last_discord_deaf = ""

    # 1. ΕΚΚΙΝΗΣΗ ΤΟΥ GUI & ΣΥΝΔΕΣΗ ΜΕ ΤΑ CUSTOM LINKS
    user_data = launch_apps_gui()
    my_links = user_data.get("links", ["", "", ""])
    links_handler = CustomLinks(my_links)

    # 2. ΑΘΟΡΥΒΗ ΛΕΙΤΟΥΡΓΙΑ Ή DEV CONSOLE 
    if user_data.get("dev_mode"):
        try:
            ctypes.windll.kernel32.FreeConsole()
            ctypes.windll.kernel32.AllocConsole()
            sys.stdout = open("CONOUT$", "w", encoding="utf-8")
            sys.stderr = open("CONOUT$", "w", encoding="utf-8")
            print("=== ESP32 Dashboard: Developer Console Active ===")
        except: pass
    else:
        try:
            hWnd = ctypes.windll.kernel32.GetConsoleWindow()
            if hWnd != 0: ctypes.windll.user32.ShowWindow(hWnd, 0)
        except: pass
    
    # ΕΝΕΡΓΟ: Discord RPC/Status Tracking
    start_discord_rpc()

    try:
        ser = serial.Serial(port_name, BAUD_RATE, timeout=0.1)
        print(f"--- 🚀 Bridge Active on {port_name} ---")
        
        print("Περιμένω 5 δευτερόλεπτα να ανοίξει η οθόνη του ESP32...")
        time.sleep(5) 
        ser.write(b"<PC_OK>\n")
        time.sleep(1)
        
        last_sync_time = 0 
        print("Ξεκινάει το Main Loop! (Ctrl+C για έξοδο)")

        # Χρονόμετρο για το Hardware Update
        last_hardware_update = time.time()
        HARDWARE_UPDATE_INTERVAL = 2.0  # Στέλνει δεδομένα κάθε 2 δευτερόλεπτα

        while True:

            current_time = time.time()
            
            # --- 🔄 SYNC LOOP (Spotify, Volume, Discord) ---
            if current_time - last_sync_time >= 1.0:
                last_sync_time = current_time
                
                # Spotify Data
                spot_data = get_spotify_detailed_data()
                if spot_data and ser:
                    for key, value in spot_data.items():
                        ser.write(f"{value}\n".encode('utf-8'))
                        time.sleep(0.01) 
                
                # Volume Sync (Από το PC προς το ESP32)
                current_vol = get_pc_volume()
                if current_vol != last_vol:
                    last_vol = current_vol
                    if ser: ser.write(f"<VOL:{current_vol}>\n".encode('utf-8'))
                
                # Discord Sync
                d_state = get_discord_state()
                if d_state["mic"] != last_discord_mic:
                    last_discord_mic = d_state["mic"]
                    cmd = "<MIC:OFF>\n" if last_discord_mic == "MUTED" else "<MIC:ON>\n"
                    if ser: ser.write(cmd.encode('utf-8'))

                if d_state["deaf"] != last_discord_deaf:
                    last_discord_deaf = d_state["deaf"]
                    cmd = "<DISC:DEAF>\n" if last_discord_deaf == "ON" else "<DISC:UNDEAF>\n"
                    if ser: ser.write(cmd.encode('utf-8'))

            # --- ΑΠΟΣΤΟΛΗ HARDWARE DATA ---
            if current_time - last_hardware_update > HARDWARE_UPDATE_INTERVAL:
                try:
                    # Παίρνουμε τα ποσοστά
                    cpu, ram, gpu = get_hardware_stats()
                    
                    # Τα στέλνουμε στο ESP32 με τη μορφή που περιμένει (Χρησιμοποιούμε ser αντί για arduino)
                    if ser:
                        ser.write(f"<CPU:{cpu}>\n".encode('utf-8'))
                        ser.write(f"<RAM:{ram}>\n".encode('utf-8'))
                        ser.write(f"<GPU:{gpu}>\n".encode('utf-8'))
                    
                    # Μηδενίζουμε το χρονόμετρο
                    last_hardware_update = current_time
                except Exception as e:
                    print(f"Hardware stats error: {e}")
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

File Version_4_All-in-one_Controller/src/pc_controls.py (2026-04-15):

import pyautogui
import comtypes
from ctypes import cast, POINTER
from comtypes import CLSCTX_ALL, GUID
from pycaw.pycaw import AudioUtilities, IAudioEndpointVolume, IMMDeviceEnumerator
import os
import subprocess

try:
    import psutil
except ImportError:
    print("Cpu fail")
try:
    import GPUtil
except ImportError:
    GPUtil = None

# ==========================================
# --- GLOBAL AUDIO INITIALIZATION ---
# ==========================================
try:
    comtypes.CoInitialize()
    
    # Ζητάμε απευθείας από τα Windows το κεντρικό ηχείο (eRender)
    CLSID_MMDeviceEnumerator = GUID("{BCDE0395-E52F-467C-8E3D-C4579291692E}")
    deviceEnumerator = comtypes.CoCreateInstance(
        CLSID_MMDeviceEnumerator,
        IMMDeviceEnumerator,
        CLSCTX_ALL
    )
    
    # 0 = eRender (Ηχεία), 1 = eMultimedia
    endpoint = deviceEnumerator.GetDefaultAudioEndpoint(0, 1)
    
    # Ενεργοποιούμε το Volume Interface για τα Ηχεία
    interface = endpoint.Activate(IAudioEndpointVolume._iid_, CLSCTX_ALL, None)
    volume_control = cast(interface, POINTER(IAudioEndpointVolume))
    
    print("✅ Το Σύστημα Ήχου (Raw API) αρχικοποιήθηκε επιτυχώς!")
except Exception as e:
    print(f"❌ Σφάλμα κατά την αρχικοποίηση του ήχου: {e}")
    volume_control = None

# --- Paths για το NirCmd (χρησιμοποιείται για το Mic Mute Toggle) ---
current_dir = os.path.dirname(os.path.abspath(__file__))
possible_nircmd_paths = [
    os.path.join(current_dir, "nircmd.exe"),
    os.path.join(current_dir, "..", "nircmd.exe")
]

# ==========================================
# --- FUNCTIONS ---
# ==========================================

def get_hardware_stats():
    """Επιστρέφει τη χρήση CPU, RAM και GPU σε ακέραια ποσοστά (0-100)"""
    # Το interval=None εξασφαλίζει ότι η εντολή δεν θα μπλοκάρει (δεν θα παγώσει) τον κώδικα
    cpu = int(psutil.cpu_percent(interval=None))
    ram = int(psutil.virtual_memory().percent)
    
    gpu = 0
    # Διαβάζουμε την κάρτα γραφικών (με ασφάλεια σε περίπτωση που δεν βρεθεί)
    if GPUtil is not None:
        gpus = GPUtil.getGPUs()
        if gpus:
            gpu = int(gpus[0].load * 100)
            
    return cpu, ram, gpu

def get_pc_volume():
    """Διαβάζει την ένταση των Windows (0-100) ΑΣΤΡΑΠΙΑΙΑ"""
    if not volume_control: return 50
    try:
        return int(volume_control.GetMasterVolumeLevelScalar() * 100)
    except Exception as e:
        print(f"[ERROR] Volume Read Failed: {e}") 
        return 50 

def set_volume(level):
    """
    Ρυθμίζει την ένταση των Windows. 
    Υποστηρίζει απόλυτες τιμές (0-100) και σχετικές τιμές ("+10", "-10").
    """
    if not volume_control or level is None: return
    
    try:
        current_vol = get_pc_volume()
        target_vol = current_vol

        # Έλεγχος αν η τιμή είναι σχετική (String με + ή -)
        if isinstance(level, str):
            if level.startswith('+'):
                target_vol = current_vol + int(level[1:])
            elif level.startswith('-'):
                target_vol = current_vol - int(level[1:])
            else:
                target_vol = int(level)
        else:
            target_vol = int(level)

        # Περιορισμός τιμών ασφαλείας μεταξύ 0 και 100
        final_level = max(0, min(100, target_vol))
        
        # Το API δέχεται τιμές από 0.0 έως 1.0
        volume_control.SetMasterVolumeLevelScalar(final_level / 100, None)
        print(f"[PC CONTROL] Volume adjusted from {current_vol}% to {final_level}%")
        
    except Exception as e:
        print(f"❌ Error setting volume: {e}")

def set_mic_volume(level):
    """Ρυθμίζει την ένταση του Μικροφώνου στα Windows (0-100)"""
    try:
        comtypes.CoInitialize() 
        devices = AudioUtilities.GetMicrophone()
        if not devices: 
            print("⚠️ Δεν βρέθηκε μικρόφωνο!")
            return
        
        interface = devices.Activate(IAudioEndpointVolume._iid_, CLSCTX_ALL, None)
        mic_volume = cast(interface, POINTER(IAudioEndpointVolume))
        
        level = max(0, min(100, int(level)))
        mic_volume.SetMasterVolumeLevelScalar(level / 100, None)
        print(f"🎤 [PC CONTROL] Microphone volume set to {level}%")
    except Exception as e:
        print(f"❌ Error setting mic volume: {e}")

def toggle_system_mic_mute():
    """Χρησιμοποιεί το NirCmd για Toggle Mute του μικροφώνου."""
    nircmd_exe = None
    for path in possible_nircmd_paths:
        if os.path.exists(path):
            nircmd_exe = path
            break
    
    if not nircmd_exe:
        print(f"❌ ΣΦΑΛΜΑ: Το nircmd.exe δεν βρέθηκε!")
        return

    try:
        # 2 = toggle
        subprocess.run([nircmd_exe, "mutesysvolume", "2", "default_record"], check=True)
        print("✅ Mic Toggled Successfully via NirCmd")
    except Exception as e:
        print(f"❌ Error toggling mic: {e}")

def boss_key():
    """Win + D shortcut (Ελαχιστοποίηση / Desktop)"""
    try:
        pyautogui.hotkey('win', 'd')
        print("[PC CONTROL] Boss Key activated!")
    except Exception as e:
        print(f"Error with Boss Key: {e}")

def toggle_camera():
    """Ανοίγει την εφαρμογή κάμερας των Windows"""
    try:
        os.system("start microsoft.windows.camera:")
        print("[PC CONTROL] Camera app toggled")
    except Exception as e:
        print(f"Error toggling camera: {e}")

def media_play_pause():
    """Play/Pause για media players"""
    try:
        pyautogui.press('playpause')
        print("[PC CONTROL] Media Play/Pause")
    except Exception as e:
        print(f"Error with Play/Pause: {e}")
